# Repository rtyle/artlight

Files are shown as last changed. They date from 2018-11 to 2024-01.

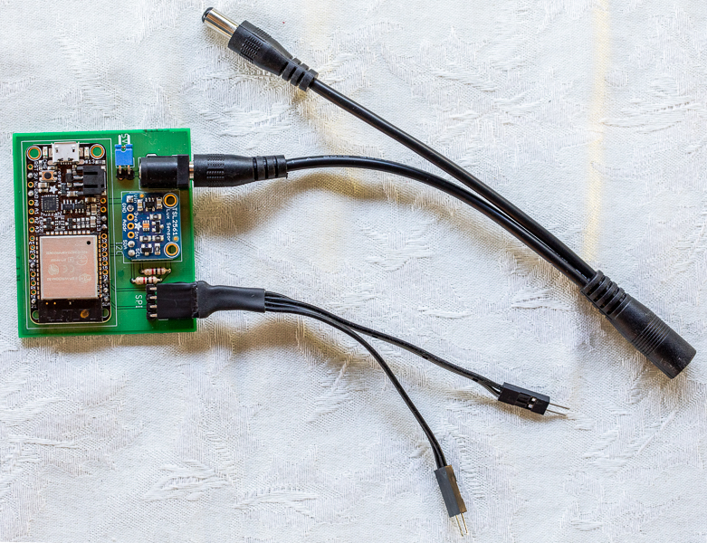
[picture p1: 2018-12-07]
project/doc/artlight.board.front.wired.jpg

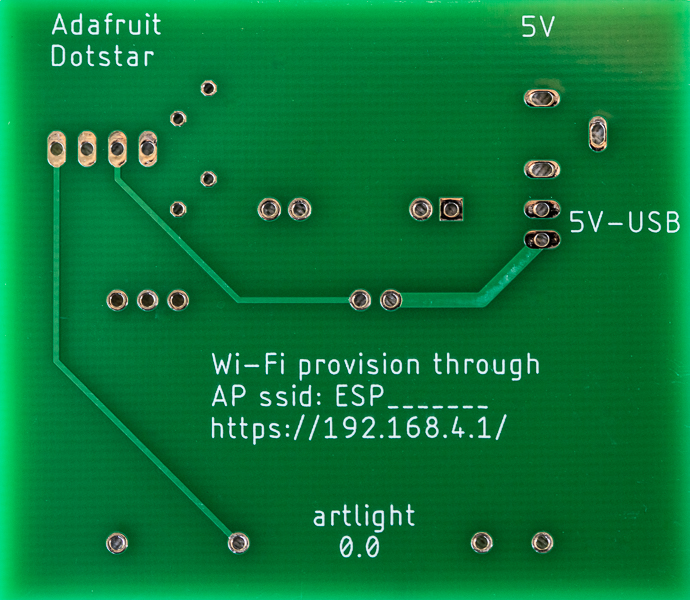
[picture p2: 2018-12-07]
project/doc/artlight.board.back.raw.jpg

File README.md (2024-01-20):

# artlight
This repository supports similar applications that artfully animate light.

Currently, there is a cornhole, wall clock, nixie tube clock and golden clock application supported by this repository.

Golden clock (LED sunflower): https://youtu.be/tHdfZooGRxo

Nixie tube clock: https://youtu.be/5ZdNDDC60QM

Wall clock: https://youtu.be/0ISKXnE9frU

## Parts

### Golden Clock Parts

* [5V 20W power supply](https://www.digikey.com/en/products/detail/cui-inc/SWI25-5-N-P5/7070092)
* [TinyPICO ESP32 development board](https://www.adafruit.com/product/4335)
* SMD 0.1" pin headers for mounting TinyPICO to TinyPICO IO PCB
* 2 position JST PH connection header (bundled in TinyPICO ESP32 development board package) for +5V TinyPICO power
* [3 position JST SH connection header](https://www.digikey.com/en/products/detail/jst-sales-america-inc/SM03B-SRSS-TB(LF)(SN)/926874) for LED SPI signals
* [4 position JST SH connection header](https://www.digikey.com/en/products/detail/sparkfun-electronics/PRT-14417/7652746) for I2C interface with light sensor
* 1024 [SK9822 5050 LEDs](https://www.amazon.com/gp/product/B07QXJSNLN)
* [Barrel connector jack](https://www.digikey.com/product-detail/en/cui-devices/PJ-036AH-SMT-TR/CP-036AHPJCT-ND/1530994) for +5V LED power
* [3 position 0.1" horizontal connection header](https://www.digikey.com/en/products/detail/harwin-inc/M20-8890345/6565716) for LED SPI signals
* [TSL2591 light sensor](https://www.digikey.com/en/products/detail/adafruit-industries-llc/1980/4990786)
* Appropriate cables and connectors for wiring harness
* [12" interior picture frame](https://www.etsy.com/listing/943351523/round-craft-frame-hump-profile-1-14)

### Nixie Tube Clock Parts

* [Bill of Materials](https://github.com/rtyle/artlight/blob/master/easyeda/projects/nixie/bom.csv), plus...
* [AC to 12V DC 1A wall mount power adapter](https://www.digikey.com/product-detail/en/cui-inc/SWI10-12-N-P5/102-4138-ND/6618698)
* 2 [Harwin 15 pin 2.54mm pitch](https://www.mouser.com/ProductDetail/855-M20-8771546) for SMT mount of Huzzah32 board
* 44 [Harwin H3161-05](https://www.digikey.com/product-detail/en/harwin-inc/H3161-05/952-2204-ND/3728169) sockets for nixie tube pins

Optional off-board ambient light sensor for automatic dimming
* [TSL2591 high dynamic range digital light sensor](https://www.adafruit.com/product/1980)
* [SparkFun Qwiic adapter](https://www.sparkfun.com/products/14495) TSL2591 qwiic mount
* 4 [Jumper SSH-003T-P0.2-H X2 12"](https://www.digikey.com/product-detail/en/jst-sales-america-inc/ASSHSSH28K305/455-3077-ND/6009453) TSL2591 qwiic cable
* 2 [Connector housing SH 4pos 1mm white](https://www.digikey.com/product-detail/en/jst-sales-america-inc/SHR-04V-S/455-1394-ND/759883) TSL2591 qwiic connectors

Optional on-board motion sensor plugin module for automatic on/off control
* [PIR detector I2C module](https://www.holtek.com/productdetail/-/vg/7M21x6)
* [Preci-Dip 851-87-006-10-001101 PCB connector](https://www.digikey.com/product-detail/en/preci-dip/851-87-006-10-001101/1212-1350-ND/3757600) PIR I2C mount

Optional base (something is required)
* 1 foot [Cast acrylic tubing 2.000" OD x .250" wall thickness](), cut into 9/16" slices. Four used as pedestals under PCB's nixie tubes.

### Cornhole and Wall Clock Parts

#### Cornhole and Wall Clock Common Parts

* [ESP32 board](https://www.adafruit.com/product/3405)
* [TSL2561 digital luminosity sensor breakout](https://www.adafruit.com/product/439)
* [DotStar digital LED strips](https://www.adafruit.com/product/2241)
* [2.1mm DC barrel jack (through hole)](https://www.adafruit.com/product/373)
* [Wi-Fi range extender (optional)](https://www.amazon.com/gp/product/B072MH1434)

#### Wall Clock Specific Parts

Additional parts for the clock application are
* [40 inch metal wall art](https://www.etsy.com/listing/614388701/round-metal-wall-art-perfect)
* [Custom PCB board for microprocessor](https://github.com/rtyle/artlight/blob/master/eagle/projects/artlight/artlight.brd)
* [Custom PCB board for 12 o'clock ray](https://github.com/rtyle/artlight/blob/master/eagle/projects/ray/ray0.brd)
* [Custom PCB board for other rays](https://github.com/rtyle/artlight/blob/master/eagle/projects/ray/ray.brd)
* [Mounting tape](https://www.amazon.com/gp/product/B00PKI7IBG)
* [Power supply](https://www.adafruit.com/product/1466)
* [Power Y splitter](https://www.amazon.com/gp/product/B06Y5GP7SF)
* [2.1mm DC barrel jack (surface mount)](https://www.sparkfun.com/products/12748)

#### Cornhole Specific Parts

Additional parts for the cornhole application are
* Cornhole board
* [Custom PCB board](https://github.com/rtyle/artlight/blob/master/eagle/projects/artlight/artlight.cornhole.brd)
* [Cornhole LED ring](https://www.amazon.com/gp/product/B01N7SRCQJ)
* [IR break beam sensor](https://www.adafruit.com/product/2168)
* [Vibration sensor](https://www.adafruit.com/product/1766)
* [On/off RGB switch](https://www.adafruit.com/product/3424)
* [Momentary RGB switch](https://www.adafruit.com/product/3423)
* [NPN bipolar transistors](https://www.adafruit.com/product/756)
* [Resistors](https://www.adafruit.com/product/2784)
* [Power bank](https://www.amazon.com/gp/product/B072MH1434)
* [Magnetic mount](https://www.amazon.com/gp/product/B01M0DUVZV)

## Construction

The PCB components were soldered on their respective boards.
When Huzzah32 is powered by USB cable, the 5V power jumper must first be removed.

### Golden Clock Construction

[LED PCB design files](https://github.com/rtyle/artlight/tree/master/easyeda/projects/golden)
and
[TinyPICO IO PCB design files](https://github.com/rtyle/artlight/tree/master/kicad/projects/golden/tinypico-io)

Solder LEDs and connectors to LED PCB.
Solder TinyPICO and connectors to TinyPICO IO PCB.
Build wire harness as necessary for mounting.

### Nixie Tube Clock Construction

[PCB design files](https://github.com/rtyle/artlight/tree/master/easyeda/projects/nixie)

For structural integrity, use a thick (>= 2.0mm) PCB.
Order PCB with a solder paste stencil.
Use the stencil to distribute solder paste for all components under the nixie tubes and solder them with a hot air gun.
Solder all other components individually, as appropriate.
Press in pin sockets and solder from the bottom.
Mount nixie tubes and place PCB on acrylic pedestals.

*WARNING*: The nixie tubes run at 170 volts.
To reduce exposure, do not plug in until tubes are mounted and PCB is placed on acrylic pedestals.

### Wall Clock Construction

[PCB design (artlight.\*) files](https://github.com/rtyle/artlight/tree/master/eagle/projects/artlight)
with
[boards for mounting LED strips on rays](https://github.com/rtyle/artlight/tree/master/eagle/projects/ray)

The microprocessor board is mounted on the back of the art with its luminosity sensor peeking through a hole drilled in the center.
Power is routed and split between the microprocessor and 12 o'clock ray boards.
SPI signals used to animate the individually addressable LEDs are cabled from the microprocessor board to the 12 o'clock board.

LED strips are mounted to the back of the wall art.
To reduce wiring complexity, the 12 rays are supported by PCBs.
12 o'clock is different so there is a special board for it.
Each ray is cut to length, an LED strip is cut to match, mounted with tape and soldered at the ends with LEDs advancing toward the center.
The ray boards are then mounted to the back of the art using more of the same tape.
Small strips are cut to bridge the arcs between ray bases, taped and soldered in place with LEDs advancing clockwise (from front!).
Starting at 12 o'clock, strips are cut and joined together with wire to skirt the perimeter of the art (clockwise, from front).
Only clock and data signals need to tunnel under the rays as 5V and GND can be tapped from the LED strip edges of adjacent rays.

### Cornhole Construction

[PCB design (artlight.cornhole.\*) files](https://github.com/rtyle/artlight/tree/master/eagle/projects/artlight)

The power bank is mounted with strong magnets under the board so that it might easily be unplugged, removed, charged, replaced and plugged back in.
Power from it may be switched on and off (with the on/off switch).
Switched power is split between the microprocessor board, the ring LED strip and the high side of the RGB LEDs in all the switches.

The R, G and B LEDs in the switches are separtely pulse-width-modulated (PWM) to mix the preferred color of each.
PWM switching is controlled indirectly through transistor circuits wired to the low side of the RGB LEDs of each switch.
The momentary switch outputs (closed to ground) are wired to the microprocessor board inputs dedicated for them.

Vibration sensors are strategically placed (for best performance) under the board.
The vibration sensor part may be changed to affect its sensitivity.
Their shared (parallel) output (closed to ground) is wired to the microprocessor board input dedicated for them.

IR break beam sensors are mounted across the cornhole ring for the best coverage (2 orthogonal pairs seems adequate).
Their shared (parallel) output (closed to ground) is wired to the microprocessor board input dedicated for them.

The LEDs that come with the cornhole LED ring are replaced with a clockwise (from the top) strip of 80 individually addressable LEDs.
Their control lines are wired to the microprocessor board output dedicated for them.
The ring is mounted under the board.
For best results, the material above the LED ring should be transparent (for example, an acrylic ring)
so that the lights under the board can be seen from above.

## Use

Applications must be provisioned on a Wi-Fi LAN.
Until this is done, they will offer their own Wi-Fi access point where they can be configured securely by a web browser (https://192.168.4.1).
The SSID and password for Wi-Fi access must be entered.
Optionally, an mDNS hostname may be given.

The reach of your Wi-Fi LAN may need to be increased to reach these devices.
This is best done by repositioning the devices and/or Wi-Fi access points.
If necessary, deploy a Wi-Fi range extender.

Once provisioned, preferences may be set for each application by pointing a web browser to the device (http://\<device\>/).
If supported, the mDNS hostname may be used to resolve the device address;
otherwise, the leased IP address will have to be resolved (perhaps manually) depending on the capabilities of the LAN's DHCP/DNS services.

The preferences page may be filled using "factory" default values or with the current values.
Changes to most will take effect immediately.
If not, then they will take effect when the form is submitted.

Preferences may be used to customize the presentation.
Brightness parameters may be set which may include use of the luminosity sensor.
The mDNS hostname of the board may be changed.
Parameters may be set in order to accurately present time in the given time zone.
Over-the-air software updates may also be performed.

## Golden Clock Use

It's "golden" because the LED layout that produces the spirals is based on the [golden ratio](https://en.wikipedia.org/wiki/Golden_ratio).

In clock mode, the length, width, curl, shape and color of each hand may be customized. During the first minute of each hour, the minute and second hands are suppressed and the hour hand is etched into a matching randomized swirling pattern.

In swirl mode, the randomized swirling pattern cycles through six different minute-long phases, each aligned to a particular set of spirals.

The number of spirals in each set are [Fibonacci numbers](https://en.wikipedia.org/wiki/Fibonacci_number) (13, 21, 34, 55, 89, 144).
The lower the number, the tighter (curlier) the spirals in the set.
Of all the Fibonacci numbers, these ones resolve best on a layout with this number of LEDs.
By default, the sets with 21, 55 and 144 spirals are used to resolve the hour, minute and second hands because they all curve the same way and most all are sufficient to resolve the units of their measure.
Unfortunately, 55 is not quite enough resolution for 60 minutes but it looks better than the spiral set of 89 because that curves the other way.
In any case, you can choose what you like.

A high quality power supply is required to power both the microcontroller and the LEDs.
It may be necessary to use separate power supplies for these.
If so, they must tolerate having their grounds tied together.

## Nixie Tube Clock Use

The bottom dot of the colon pulses at 30 beats per minute (a second on and a second off).
The top dot of the colon pulses at 31 beats per minute.
This results in pulsing dots that are in phase at the beginning of the minute.
They separate more as mid-minute is approached and come back together again as the next minute is approached.
Thus the colon is a very crude seconds display.

Dimming controls should be slid all the way to the left to disable dimming; otherwise, dimming will start to occur as it gets dark.
The further to the right the dimming control is set, the more dimming will be done.
When slid all the way to the right, the controlled element will dim to black when the room is black.

In an effort to combat [nixie tube cathode poisoning](https://www.google.com/search?q=nixie+tube+cathode+poisoning)
the clock will not display minutes during the first minute of every hour.
Instead, the normal minutes-places will cycle through digits that are not normally used there.
For hours less than 10, the tens-of-hours place will similarly cycle.
The display can also be temporarily put in a Clean mode (or other modes) until expectations are met.

## Wall Clock Use

There are no additional preferences for the clock application.

The clock will present time by animating hour, minute and second indicators using the LEDs mounted to the back of the art.
Hour and minute indicators will animate up and down the rays and across the inner arcs that connect them.
The second indicator will sweep across the perimeter.

## Cornhole Use

The cornhole "preferences" page may be used to keep score.
In fact, unless explicitly accessed through a URL with a preferences path (http://\<device\>/preferences), scoring is the only thing allowed.

Changing most preferences (including scoring) will be shared between boards that have been configured to use the same network port number.
For this to work effectively, only the two boards used in a cornhole game should share the same port number and each must be reachable from the other on the same network.

A preference may be used to control what the ring LED strip indicates:
* The score of each team
* The time
* Various animations

Regardless of what the ring indicates:

A short press of a momentary switch will increment the score of the associated team.
A long press of a momentary switch will decrement the score of the associated team while held.
While decrementing, if the other switch is down too then the score is reset to 0 (hold both to reset both to 0).

Vibration from the board will cause a short "lightning strike" animation to be presented over the existing ring indication.
A break in the ring's IR beam sensors will cause a short "fireworks" animation to be presented over the existing ring indication.

## Software Build, Deploy and Monitor

These projects were built on a Fedora Linux platform.
Your mileage may vary elsewhere.

Get artlight source code with its dependencies

    git clone http://github.com/rtyle/artlight.git
    cd artlight
    git submodule update --init --recursive
    (cd esp-idf; git apply ../time.c.patch)
  
[Create certificates](https://github.com/rtyle/artlight/blob/master/project/README.certificates.txt)

Install tools required by esp-idf in esp-idf-tools.

    IDF_TOOLS_PATH=esp-idf-tools esp-idf/install.sh

(Re)establish build environment.

    . esp-idf-export.sh

Select application (choose one).

    application=clock
    application=cornhole
    application=golden
    application=nixie

Build application.

    (cd project; ArtlightApplication=$application idf.py fullclean reconfigure build)

Grant user access to USB serial devices then **relogin** to get access.

    sudo usermod -a -G dialout $USER

Identify serial port to connected device.
For example,

    port=/dev/ttyUSB0

Prepare connected device and deploy application.

    (cd project; idf.py -p $port erase_flash erase_otadata)
    (cd project; idf.py -p $port flash)

Monitor serial output from device.

    (cd project; idf.py -p $port monitor)

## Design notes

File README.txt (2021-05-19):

# git

	git clone git@github.com:rtyle/artlight.git

	cd artlight

# esp-idf

	# give $USER access to /dev/ttyUSB* and relogin
	# this is needed to allow for USB communication with esp32
	sudo usermod -a -G dialout $USER

	# toolchain prerequisites
	# https://docs.espressif.com/projects/esp-idf/en/stable/esp32/get-started/linux-setup.html

		sudo dnf install git wget flex bison gperf python3 python3-pip python3-setuptools cmake ninja-build ccache dfu-util libusbx

	# esp-idf
	# https://docs.espressif.com/projects/esp-idf/en/stable/esp32/get-started/index.html#get-started-get-esp-idf

		# install esp-idf as a submodule under project
		git submodule add https://github.com/espressif/esp-idf.git

		# update now (and/or later)

			(
				cd esp-idf
				git fetch
				git checkout v4.3-beta3
				git submodule update --init --recursive
			)

# esp-idf-tools

	# install tools required by esp-idf in esp-idf-tools
	IDF_TOOLS_PATH=esp-idf-tools esp-idf/install.sh

	install /dev/stdin esp-idf-export.sh <<EOF
export IDF_TOOLS_PATH=$(realpath esp-idf-tools); . esp-idf/export.sh
EOF

	# (re)establish this environment for idf.py and eclipse actions

		. esp-idf-export.sh

	echo esp-idf-tools > .gitignore

# eclipse

	sudo dnf install eclipse eclipse-cdt eclipse-mpc

	# fedora 34 packaged eclipse does not work with espressif/idf-eclipse-plugin
	# https://github.com/espressif/idf-eclipse-plugin/issues/260
	# download from eclipse.org

		curl https://www.eclipse.org/downloads/download.php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 | tar xzf -
		mv eclipse ~/eclipse-2021-03

	# get rid of old eclipse artifacts

		rm -rf ~/.{eclipse,p2}

# https://docs.espressif.com/projects/esp-idf/en/latest/get-started/eclipse-setup.html

	echo .metadata >> .gitignore

	(. esp-idf-export.sh; ~/eclipse-2021-03/eclipse >/dev/null 2>&1 &)

		#! set workspace to here

		Help: Install New Software...: Add...: 

			# espressif/idf-eclipse-plugin

				Name:		espressif/idf-eclipse-plugin latest
				Location:	https://dl.espressif.com/dl/idf-eclipse-plugin/updates/latest/

				Add

				X Espressif IDF

				Install anyway
				Restart Now

		File: New: Project...

			Wizard: Espressif: Espressif IDF Project
			Project name: project

		Project Explorer: <project>

			toolbar: Launch Target
				Name:		esp32
				IDF Target:	esp32
				Serial Port:	/dev/ttyUSB1

			toolbar: Build

			toolbar: Open a Terminal
				Choose terminal:	ESP-IDF Serial Monitor
					this doesn't work
				Choose terminal:	Serial Terminal

			toolbar: Launch in 'Run' mode

		<project>: Run As: Run Configurations...
			ESP-IDF Application
				project
					Common
						Display in favorites menu
							0 Debug
							X Run
					Apply
					Close

		<project>: Debug As: Debug Configurations...
			ESP-IDF GDB OpenOCD Debugging
				New Configuration
					Name:	project debugger
					Debugger
						OpenOCD Setup
							Executable path:	openocd
							Config options:		-f board/esp32-wrover-kit-3.3v.cfg
						GDB Client Setup
							Actual executable:	xtensa-esp32-elf-gdb
					Startup
						Initialization Commands
							0 Enable ARM semihosting
					Common
						Display in favorites menu
							X Debug
							0 Run
					Apply
					Close

		Project Explorer: <project>

			toolbar: Launch Configuration: project debugger
			toolbar: Launch Mode: Debug
			toolbar: Launch in 'Debug' mode

				# auto change to debug perspective
				# find code stopped at app_main entry point

		exit eclipse

	rm -rf project/build
	rm project/sdkconfig*

	echo build	>> project/.gitignore
	echo sdkconfig	>> project/.gitignore
	echo *.old	>> project/.gitignore
	echo *.swp	>> project/.gitignore

	git add README.txt .gitignore project
	git commit -m 'idf-eclipse-plugin'

eclipse preferences

	General: Editors: Text Editors
		Displayed tab width:	8
		X Show print margin
		X Show line numbers
		X Show whitespace characters

	C/C++: Code Style: Formatter
		Active profile:	K&R [built-in]: Edit...
			Profile Name: K&R [built-in] sw=4 ts=8
				Tab policy:		Mixed
				Indentation size:	4
				Tab size:		8

	exit eclipse

	git add README.txt
	git commit -m 'eclipse preferences'

configuring build type and
flashing from command line
	
	# pick one
	application=clock
	application=cornhole
	application=nixie
	application=golden

	# clean
	(cd project; ArtlightApplication=$application idf.py fullclean)

	# reconfigure for build type
	(cd project; ArtlightApplication=$application idf.py reconfigure -DCMAKE_BUILD_TYPE=Release)
	(cd project; ArtlightApplication=$application idf.py reconfigure -DCMAKE_BUILD_TYPE=Debug)

	# build
	(cd project; idf.py build)

	# identify serial port to connected device
	port=/dev/ttyUSB0

	# prepare connected device and deploy application
	(cd project; idf.py -p $port erase_flash erase_otadata)
	(cd project; idf.py -p $port flash)

	# monitor serial output from device
	(cd project; idf.py -p $port monitor)

# OTA service

	(cd project/build; openssl s_server -WWW -key ../certificates/ota_ca_key.pem -cert ../certificates/ota_ca_cert.pem)

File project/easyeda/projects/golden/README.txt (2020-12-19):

golden.html is a way to play with the PCB layout in a web browser
as well as a way to playing with animation of such.

While pcb.json can be uploaded into the EasyEDA online editor ...
https://easyeda.com/editor
... it is too large to save to cloud storage.
Because it cannot be saved first, the online editor will not make gerber files.
Instead, the EasyEDA offline editor must be used.

Unfortunately, the size of the gerber.zip archive created by the offline editor
is too large for JLCPCB.
The contents of this EasyEDA gerber.zip archive is captured
under the gerber directory.
7zip was used to remove the TopSilk layer and recompress it
to a smaller size

	(cd gerber; 7z a ../gerber.zip $(ls Gerber* | grep -v TopSilk)

The SK9822 LED LINK symbol, used for each LED in the schematic and pcb, is captured in

	SK9822LEDLINK.json

The SK9822 LED LINK symbol is referenced by its uuid in the following scripts

	createStrip.js	create and layout all the LEDs so that they are linked
	orderStrip.js	reposition LEDs according to the itemOrder they were created in

The following scripts were used to layout the PCB

	goldenPath.js		wend the ordered LEDs through their places
	goldenRing.js		create a COPPERAREA that covers all the LEDs
	centerOfSelected.js	used to calculate center of board outline

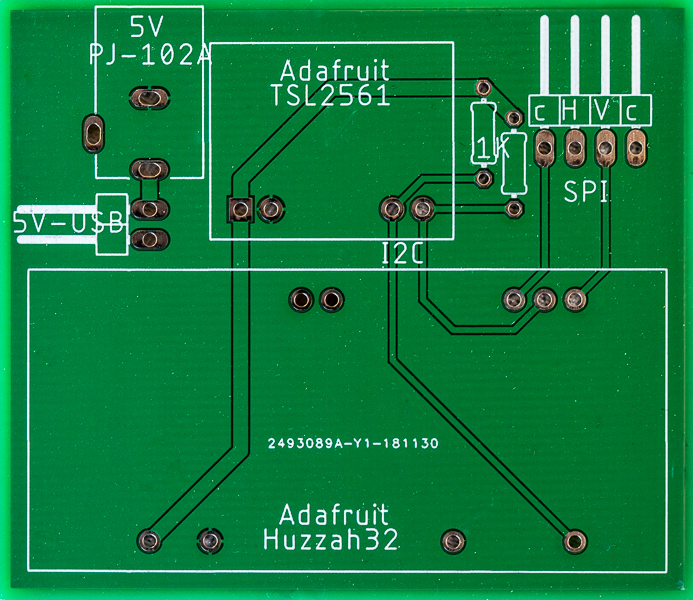
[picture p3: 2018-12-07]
project/doc/artlight.board.front.raw.jpg

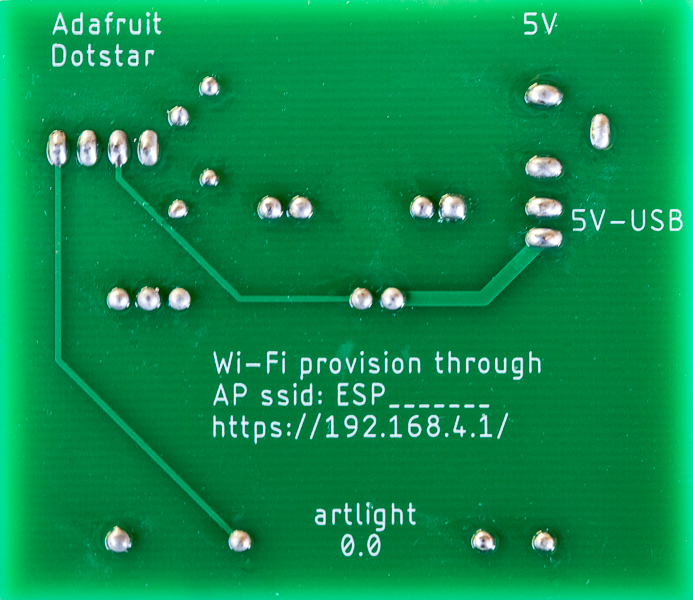
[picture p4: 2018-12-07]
project/doc/artlight.board.back.cooked.jpg

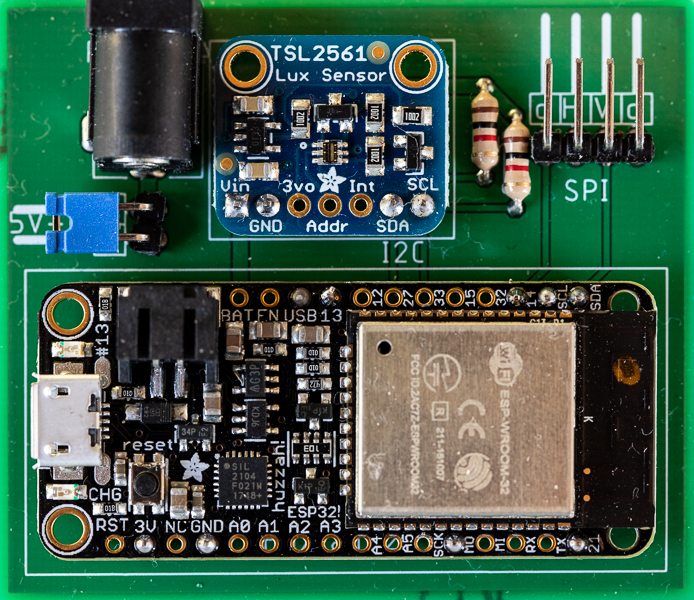
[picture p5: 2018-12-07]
project/doc/artlight.board.front.cooked.jpg

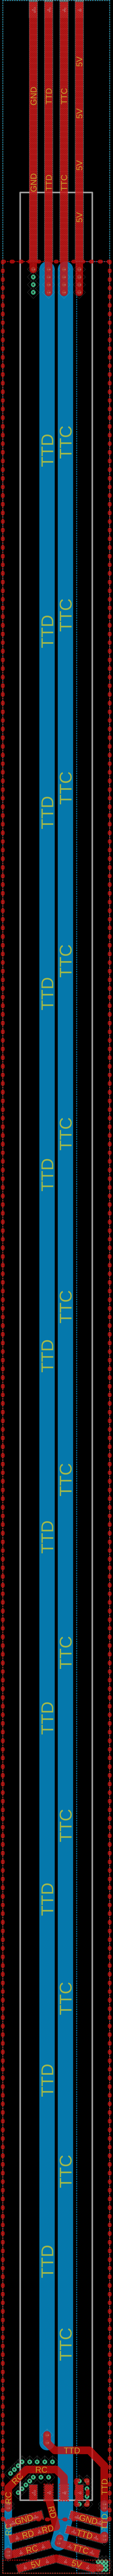
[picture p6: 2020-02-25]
project/eagle/projects/ray/ray.png

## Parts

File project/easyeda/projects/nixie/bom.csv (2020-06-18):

ID | Name | Designator | Footprint | Quantity | Manufacturer Part | Manufacturer | Supplier | Supplier Part | link
1 | R|Z568M nixie tube | NX00,NX10,NX20,NX30 | R|Z568M NIXIE TUBE BOTTOM VIEW | 4 |  |  |  |  | https://www.daliborfarny.com/product/rz568m-nixie-tube/
2 | Huzzah32 | MPU0 | HUZZAH32 SMT | 1 | 3405 | Adafruit | Digi-Key | 1528-2181-ND
3 | V78E05-1000-SMT | PS+5V | CUI V78E-1000-SMT | 1 | V78E05-1000-SMT | CUI | Digi-Key | 102-5033-1-ND | https://www.digikey.com/product-detail/en/cui-inc/V78E05-1000-SMT-TR/102-5033-1-ND/9649684
4 | 8.2K 1W | R0A,R1A,R2A,R3A | R2512 | 4 | CRCW25128K20JNEG | Vishay Dale | Digi-Key | 541-8.2KXCT-ND | https://www.digikey.com/product-detail/en/vishay-dale/CRCW25128K20JNEG/541-8-2KXCT-ND/1178603
5 | 22uF 16V | CPS+5VO | C1210 | 1 | C1210C226K4RAC7800 | KEMET | Digi-Key | 399-11662-1-ND | https://www.digikey.com/product-detail/en/kemet/C1210C226K4RAC7800/399-11662-1-ND/5023257
6 | R|Z568M colon tube | NXC0 | R|Z568M COLON TUBE BOTTOM VIEW | 1 | R|Z568M colon tube | Dalibor Farny |  |  | http://docs.daliborfarny.com/doc/separator-tube-rz568m/
7 | SK9822 LED | D00,D01,D10,D11,D20,D21,D30,D31 | SK9822 LED | 8 | 2343 | Adafruit | Digi-Key | 1528-1436-ND | https://www.digikey.com/products/en?mpart=2343&v=1528
8 | 68K 1W | RNCL,RNCR | R2512 | 2 | CRCW251268K0JNEG | Vishay Dale | Digi-Key | 541-68KXCT-ND | https://www.digikey.com/product-detail/en/vishay-dale/CRCW251268K0JNEG/541-68KXCT-ND/1178625
9 | 10uF 50V | CPS+5VI | C1210 | 1 | C1210C106K5RACTU | KEMET | Digi-Key | 399-11629-1-ND | https://www.digikey.com/product-detail/en/kemet/C1210C106K5RACTU/399-11629-1-ND/4918885
10 | NXP PCA9685 TSSOP28 | U00,U10,U20,U30 | SOT361-1 | 4 | PCA9685PW/Q900,118 | NXP USA Inc. | Digi-Key | 568-5931-1-ND | https://www.digikey.com/product-detail/en/nxp-usa-inc/PCA9685PW-Q900-118/568-5931-1-ND/2531218
11 | SMMBTA42LT1G | Q00,Q01,Q02,Q03,Q04,Q05,Q06,Q07,Q08,Q09,Q10,Q11,Q12,Q13,Q14,Q15,Q16,Q17,Q18,Q19,Q1L,Q20,Q21,Q22,Q23,Q24,Q25,Q26,Q27,Q28,Q29,Q2R,Q30,Q31,Q32,Q33,Q34,Q35,Q36,Q37,Q38,Q39 | SOT-23-3_L2.9-W1.6-P1.90-LS2.8-BR | 42 | SMMBTA42LT1G | ON Semiconductor | Digi-Key | SMMBTA42LT1GOSCT-ND | https://www.digikey.com/product-detail/en/on-semiconductor/SMMBTA42LT1G/SMMBTA42LT1GOSCT-ND/8538921
12 | Holtek HT7M21xx | U1 | PRECI-DIP 851-87-006-40-001101 | 1 | HT7M21xx | Holtek | Mouser | HT7M21xx
13 | 1uF 16V | C00,C10,C20,C30 | C0603 | 4 | C0603C105K8RACTU | KEMET | Digi-Key | 399-11133-1-ND | https://www.digikey.com/product-detail/en/kemet/C0603C105K8RACTU/399-11133-1-ND/4357815
14 | 2.2uF 450V | CPS+170VO0 | C2220 | 1 | C5750X6S2W225K250KA | TDK Corporation | Digi-Key | 445-7781-1-ND | https://www.digikey.com/product-detail/en/tdk-corporation/C5750X6S2W225K250KA/445-7781-1-ND/2733853
15 | 0.1uF 630V | CPS+170VO1 | C1812 | 1 | CGA8N4X7R2J104K230KA | TDK Corporation | Digi-Key | 445-7922-1-ND | https://www.digikey.com/product-detail/en/tdk-corporation/CGA8N4X7R2J104K230KA/445-7922-1-ND/2781426
16 | NCH8200HV | PS+170V | NCH8200HV SMD | 1 | NCH8200HV | nixieclock.org | Amazon | B074S2T7X3 | https://www.amazon.com/%E3%80%90Genuine%E3%80%91NCH8200HV-Voltage-Module-Nixie-Clock/dp/B074S2T7X3
17 | Header-Male-2.54_1x2 | H0 | HARWIN M20-8890245 | 1 | M20-8890245 | Harwin | Digi-Key | 952-3231-ND | https://www.digikey.com/product-detail/en/harwin-inc/M20-8890245/952-3231-ND/6565715
18 | SM04B-SRSS-TB (LF)(SN) QWIIC | CN0 | CONN-SMD_4P-P1.00_SM04B-SRSS-TB(LF)(SN) | 1 | PRT-14417 | SparkFun Electronics | Digi-Key | PRT-14417-ND | https://www.digikey.com/product-detail/en/sparkfun-electronics/PRT-14417/PRT-14417-ND/7652746
19 | PJ-036AH-SMT-TR | J+12V | CUI PJ-036AH-SMT-TR | 1 | PJ-036AH-SMT-TR | CUI | Digi-Key | CP-036AHPJCT-ND | https://www.digikey.com/product-detail/en/cui-devices/PJ-036AH-SMT-TR/CP-036AHPJCT-ND/1530994
20 | 1K 1/10W | RI2C0CLK,RI2C0SDA,R00,R01,R02,R03,R04,R05,R06,R07,R08,R09,R10,R11,R12,R13,R14,R15,R16,R17,R18,R19,R1L,R20,R21,R22,R23,R24,R25,R26,R27,R28,R29,R2R,R30,R31,R32,R33,R34,R35,R36,R37,R38,R39 | R0603 | 44 | CRCW06031K00FKEA | Vishay Dale | Digi-Key | 541-1.00KHCT-ND | https://www.digikey.com/product-detail/en/vishay-dale/CRCW06031K00FKEA/541-1-00KHCT-ND/1179809
21 | 1K 0603 | RI2C1SDA | R0603 | 1 | CRCW06031K00FKEA | Vishay Dale | Digi-Key | 541-1.00KHCT-ND | https://www.digikey.com/product-detail/en/vishay-dale/CRCW06031K00FKEA/541-1-00KHCT-ND/1179809
22 | 1K 1206 | RI2C1CLK | R1206 | 1 | CRCW12061K00FKEA | Vishay Dale | Digi-Key | 541-1.00KFCT-ND | https://www.digikey.com/product-detail/en/vishay-dale/CRCW12061K00FKEA/541-1.00KFCT-ND/1181760

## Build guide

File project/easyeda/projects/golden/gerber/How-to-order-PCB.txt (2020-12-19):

How to Order PCB

Please refer to:
https://docs.easyeda.com/en/PCB/Order-PCB

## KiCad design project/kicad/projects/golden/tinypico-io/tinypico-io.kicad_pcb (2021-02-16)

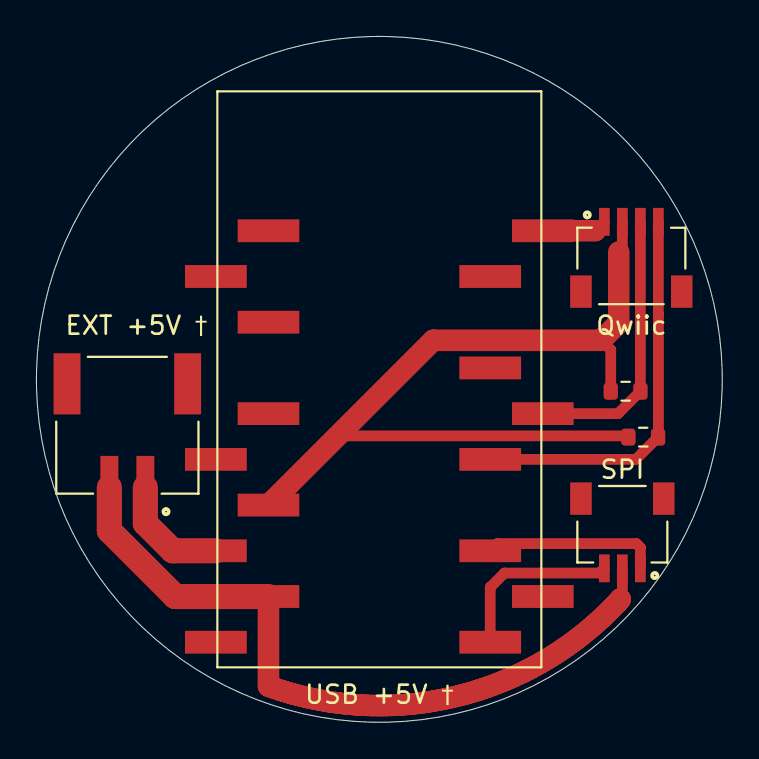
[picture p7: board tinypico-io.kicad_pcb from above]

Board: 2 copper layers, 38.1 x 38.1 mm, 6 parts (0 on the bottom side), 8 nets.

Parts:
J1: S2B-PH-SM4-TB(LF)(SN); JST_S2B-PH-SM4-TB(LF)(SN)
J2: SM03B-SRSS-TB(LF)(SN); JST_SM03B-SRSS-TB(LF)(SN)
J3: SM04B-SRSS-TB(LF)(SN); JST_SM04B-SRSS-TB(LF)(SN)
R1, R2: 1K; R_0603_1608Metric
U1: TSM-110-01-L-SV; TinyPICO

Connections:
+5V: J1.1, U1.3
/3V3: J3.2, R1.1, R2.1, U1.4
GND: J1.2, J2.2, U1.2
GND1: J3.1, U1.11
MOSI: J2.3, U1.20
SCK: J2.1, U1.18
SCL: J3.4, R2.2, U1.16
SDA: J3.3, R1.2, U1.15

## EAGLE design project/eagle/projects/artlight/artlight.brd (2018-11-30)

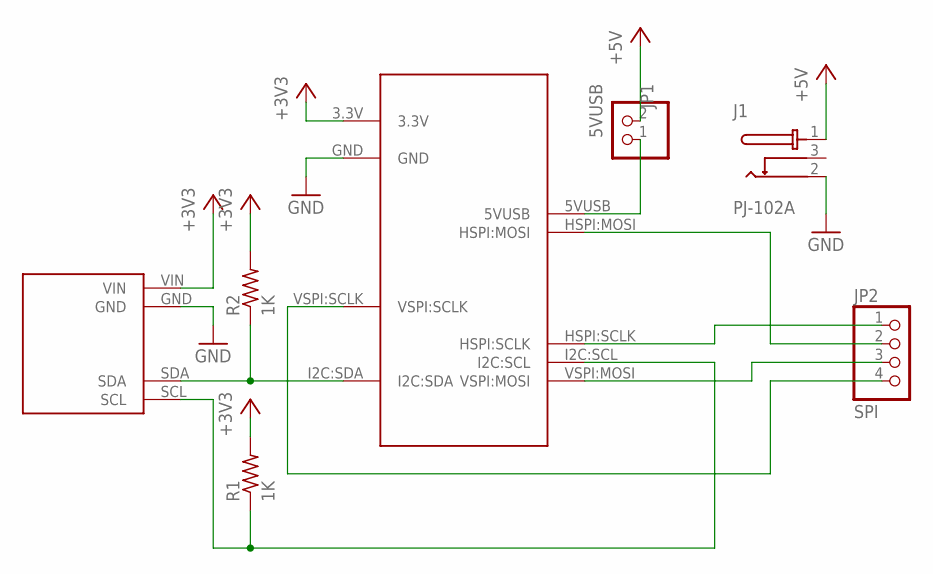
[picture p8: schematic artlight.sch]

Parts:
J1: PJ-102A; CUI_PJ-102A
JP1: 5VUSB; 1X02/90
JP2: SPI; 1X04/90
R1, R2: 1K; 0204/7
U$1: HUZZAH32-ARTLIGHT; FEATHERWING-ARTLIGHT
U$3: TSL2561-ARTLIGHT

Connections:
3: J1.3
5VUSB: JP1.1, U$1.5VUSB
+3V3: R1.2, R2.2, U$1.3.3V, U$3.VIN
+5V: J1.1, JP1.2
GND: J1.2, U$1.GND, U$3.GND
HSPI-MOSI: JP2.2, U$1.HSPI:MOSI
I2C-SCL: R1.1, U$1.I2C:SCL, U$3.SCL
I2C-SDA: R2.1, U$1.I2C:SDA, U$3.SDA
unnamed: JP2.3, U$1.VSPI:MOSI
unnamed: JP2.1, U$1.HSPI:SCLK
VSPI-SCLK: JP2.4, U$1.VSPI:SCLK

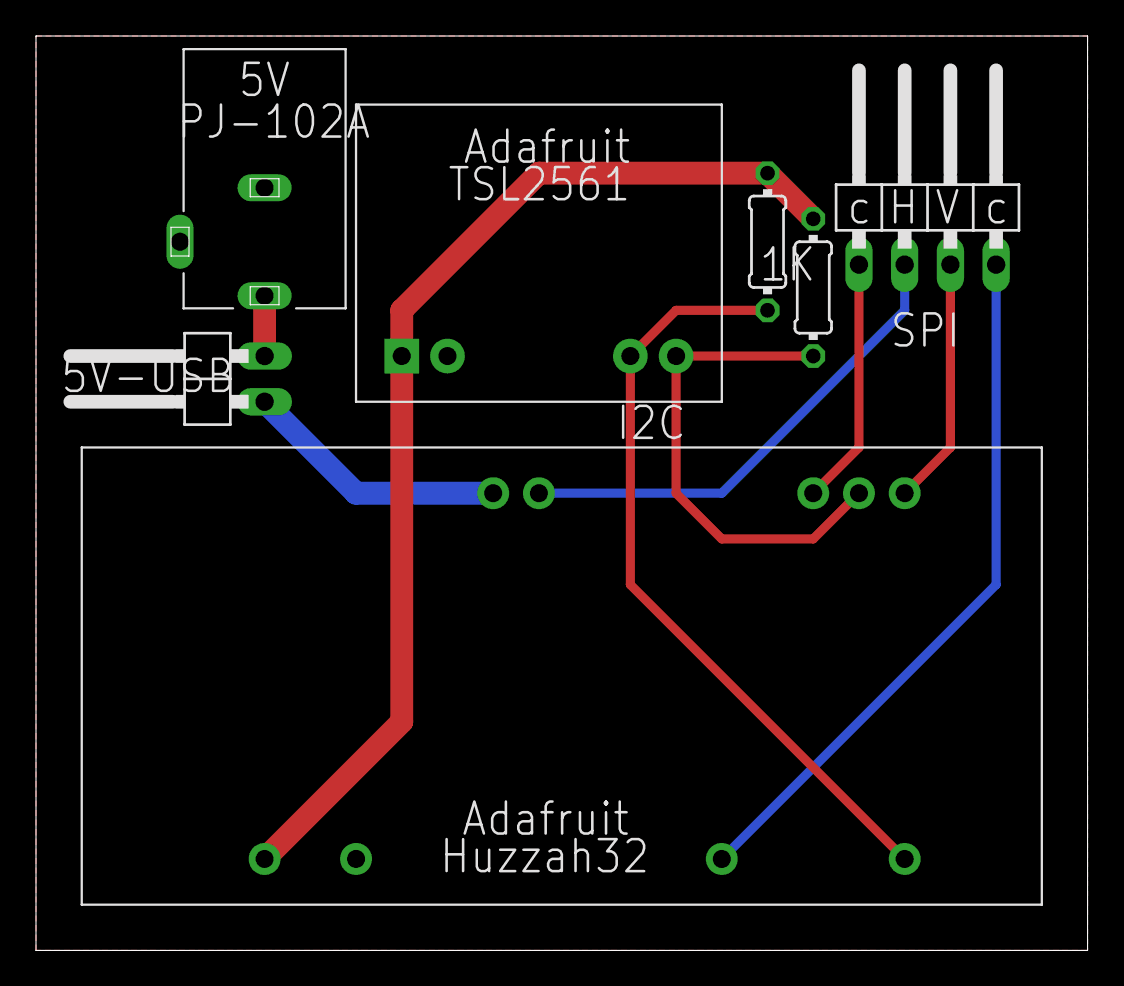
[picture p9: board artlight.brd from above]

Board: 2 copper layers, 58.4 x 50.8 mm, 7 parts (0 on the bottom side), 10 nets.

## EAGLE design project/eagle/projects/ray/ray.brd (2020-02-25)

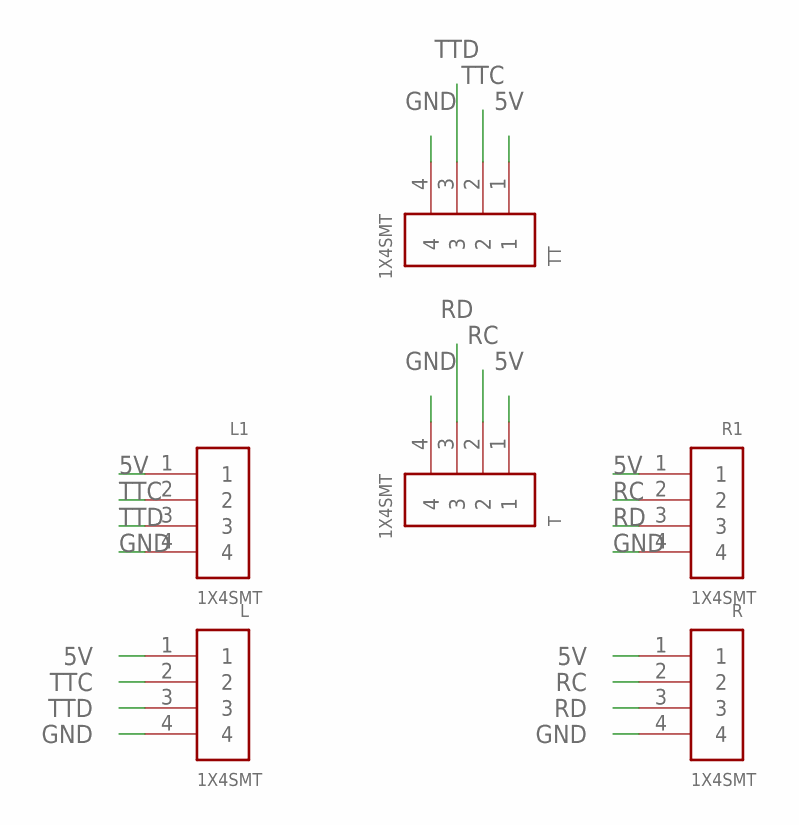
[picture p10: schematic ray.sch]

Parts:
L, L1: 1X4SMT; 1X4-SMT
R, R1: 1X4SMT; 1X4-SMT
T: 1X4SMT; 1X4-SMT
TT: 1X4SMT; 1X4-SMT

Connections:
5V: L.1, L1.1, R.1, R1.1, T.1, TT.1
GND: L.4, L1.4, R.4, R1.4, T.4, TT.4
RC: R.2, R1.2, T.2
RD: R.3, R1.3, T.3
TTC: L.2, L1.2, TT.2
TTD: L.3, L1.3, TT.3

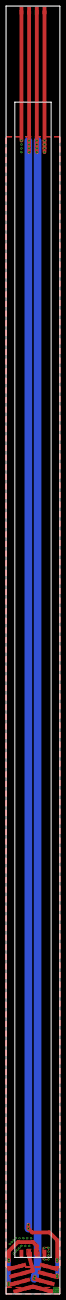
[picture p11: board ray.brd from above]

Board: 2 copper layers, 17.8 x 425.4 mm, 6 parts (0 on the bottom side), 6 nets.

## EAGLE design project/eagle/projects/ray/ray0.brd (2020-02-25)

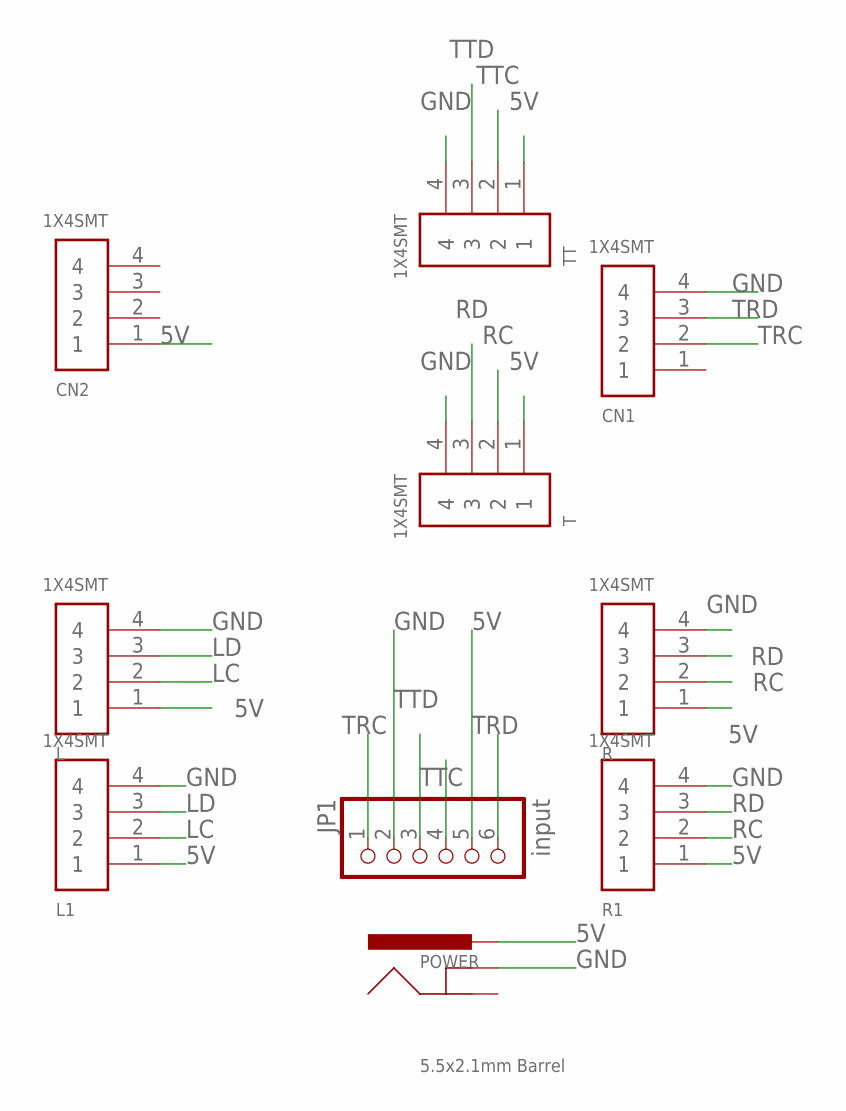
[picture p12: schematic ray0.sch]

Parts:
CN1, CN2: 1X4SMT; 1X4-SMT
JP1: input; 1X06
L, L1: 1X4SMT; 1X4-SMT
POWER: 5.5x2.1mm Barrel; POWER_JACK_SMD
R, R1: 1X4SMT; 1X4-SMT
T: 1X4SMT; 1X4-SMT
TT: 1X4SMT; 1X4-SMT

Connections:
5V: CN2.1, JP1.5, L.1, L1.1, POWER.VIN0 (PWR), POWER.VIN1 (PWR), R.1, R1.1, T.1, TT.1
GND: CN1.4, JP1.2, L.4, L1.4, POWER.GND (GNDBREAK), R.4, R1.4, T.4, TT.4
LC: L.2, L1.2
LD: L.3, L1.3
RC: R.2, R1.2, T.2
RD: R.3, R1.3, T.3
TRC: CN1.2, JP1.1
TRD: CN1.3, JP1.6
TTC: JP1.4, TT.2
TTD: JP1.3, TT.3

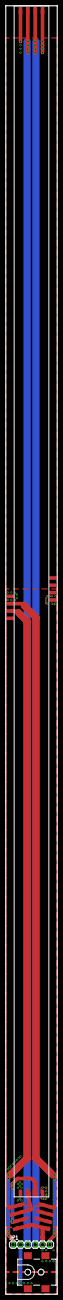
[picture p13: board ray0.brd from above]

Board: 2 copper layers, 17.8 x 445.5 mm, 10 parts (0 on the bottom side), 10 nets.

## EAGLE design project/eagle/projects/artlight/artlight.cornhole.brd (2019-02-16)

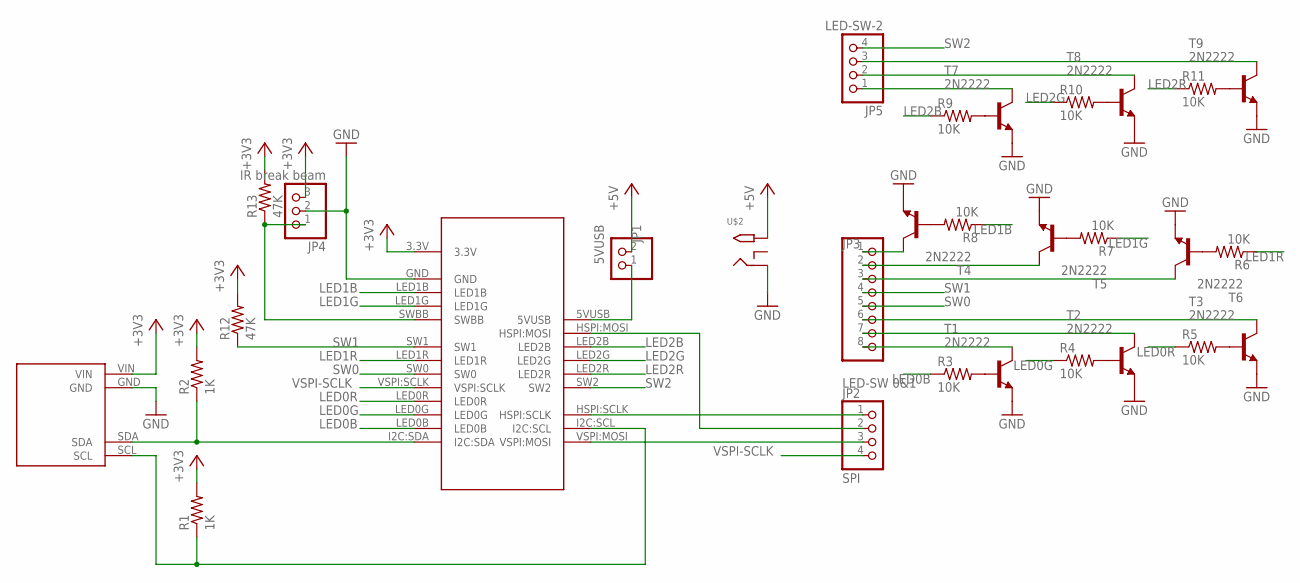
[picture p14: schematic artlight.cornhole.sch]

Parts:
JP1: 5VUSB; 1X02
JP2: SPI; 1X04
JP3: LED-SW 0&1; 1X08
JP4: IR break beam; 1X03
JP5: LED-SW-2; 1X04
R1, R2: 1K; 0204/7
R3, R4, R5, R6, R7, R8, R9, R10, R11: 10K; 0204V
R12, R13: 47K; 0204/7
T1, T2, T3, T4, T5, T6, T7, T8, T9: 2N2222; TO92-EBC-OVAL
U$1: HUZZAH32-ARTLIGHT.CORNHOLE; FEATHERWING-ARTLIGHT.CORNHOLE
U$2: 2.1MMJACKTHM; PJ-102A
U$3: TSL2561-ARTLIGHT

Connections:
5VUSB: JP1.1, U$1.5VUSB
+3V3: JP4.3, R1.2, R2.2, R12.2, R13.2, U$1.3.3V, U$3.VIN
+5V: JP1.2, U$2.TIP
GND: JP4.2, T1.E, T2.E, T3.E, T4.E, T5.E, T6.E, T7.E, T8.E, T9.E, U$1.GND, U$2.RING, U$3.GND
HSPI-MOSI: JP2.2, U$1.HSPI:MOSI
HSPI-SCLK: JP2.1, U$1.HSPI:SCLK
I2C-SCL: R1.1, U$1.I2C:SCL, U$3.SCL
I2C-SDA: R2.1, U$1.I2C:SDA, U$3.SDA
LED0B: R3.1, U$1.LED0B
LED0B-BASE: R3.2, T1.B
LED0B-PIN: JP3.8, T1.C
LED0G: R4.1, U$1.LED0G
LED0G-BASE: R4.2, T2.B
LED0G-PIN: JP3.7, T2.C
LED0R: R5.1, U$1.LED0R
LED0R-BASE: R5.2, T3.B
LED0R-PIN: JP3.6, T3.C
LED1B: R8.1, U$1.LED1B
LED1B-BASE: R8.2, T4.B
LED1B-PIN: JP3.1, T4.C
LED1G: R7.1, U$1.LED1G
LED1G-BASE: R7.2, T5.B
LED1G-PIN: JP3.2, T5.C
LED1R: R6.1, U$1.LED1R
LED1R-BASE: R6.2, T6.B
LED1R-PIN: JP3.3, T6.C
LED2B: R9.1, U$1.LED2B
LED2B-BASE: R9.2, T7.B
LED2B-PIN: JP5.1, T7.C
LED2G: R10.1, U$1.LED2G
LED2G-BASE: R10.2, T8.B
LED2G-PIN: JP5.2, T8.C
LED2R: R11.1, U$1.LED2R
LED2R-BASE: R11.2, T9.B
LED2R-PIN: JP5.3, T9.C
SW0: JP3.5, U$1.SW0
SW1: JP3.4, R12.1, U$1.SW1
SW2: JP5.4, U$1.SW2
SWBB: JP4.1, R13.1, U$1.SWBB
VSPI-MOSI: JP2.3, U$1.VSPI:MOSI
VSPI-SCLK: JP2.4, U$1.VSPI:SCLK

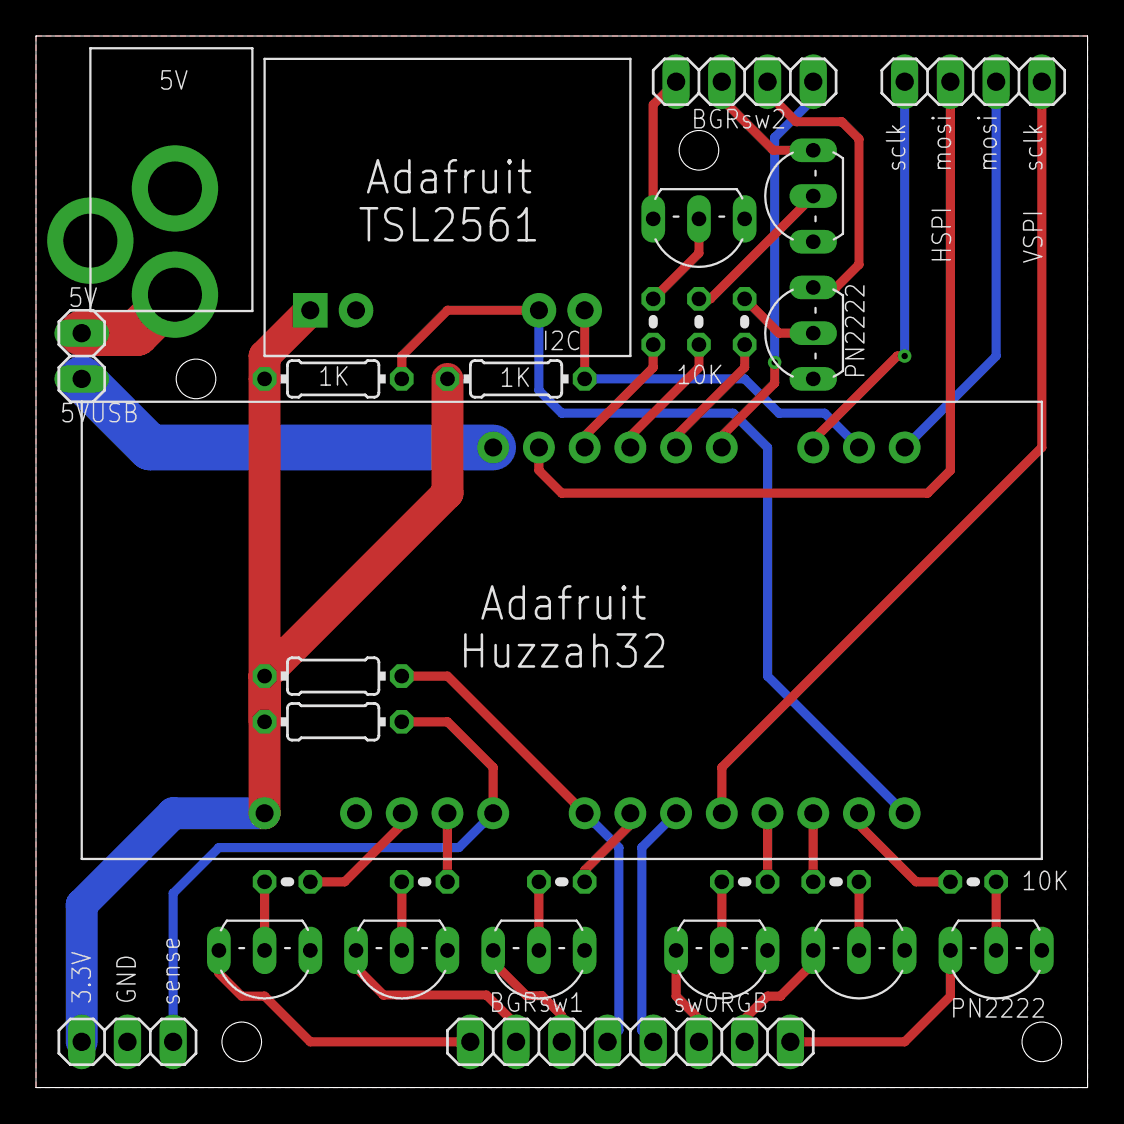
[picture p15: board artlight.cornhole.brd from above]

Board: 2 copper layers, 58.4 x 58.4 mm, 30 parts (0 on the bottom side), 41 nets.

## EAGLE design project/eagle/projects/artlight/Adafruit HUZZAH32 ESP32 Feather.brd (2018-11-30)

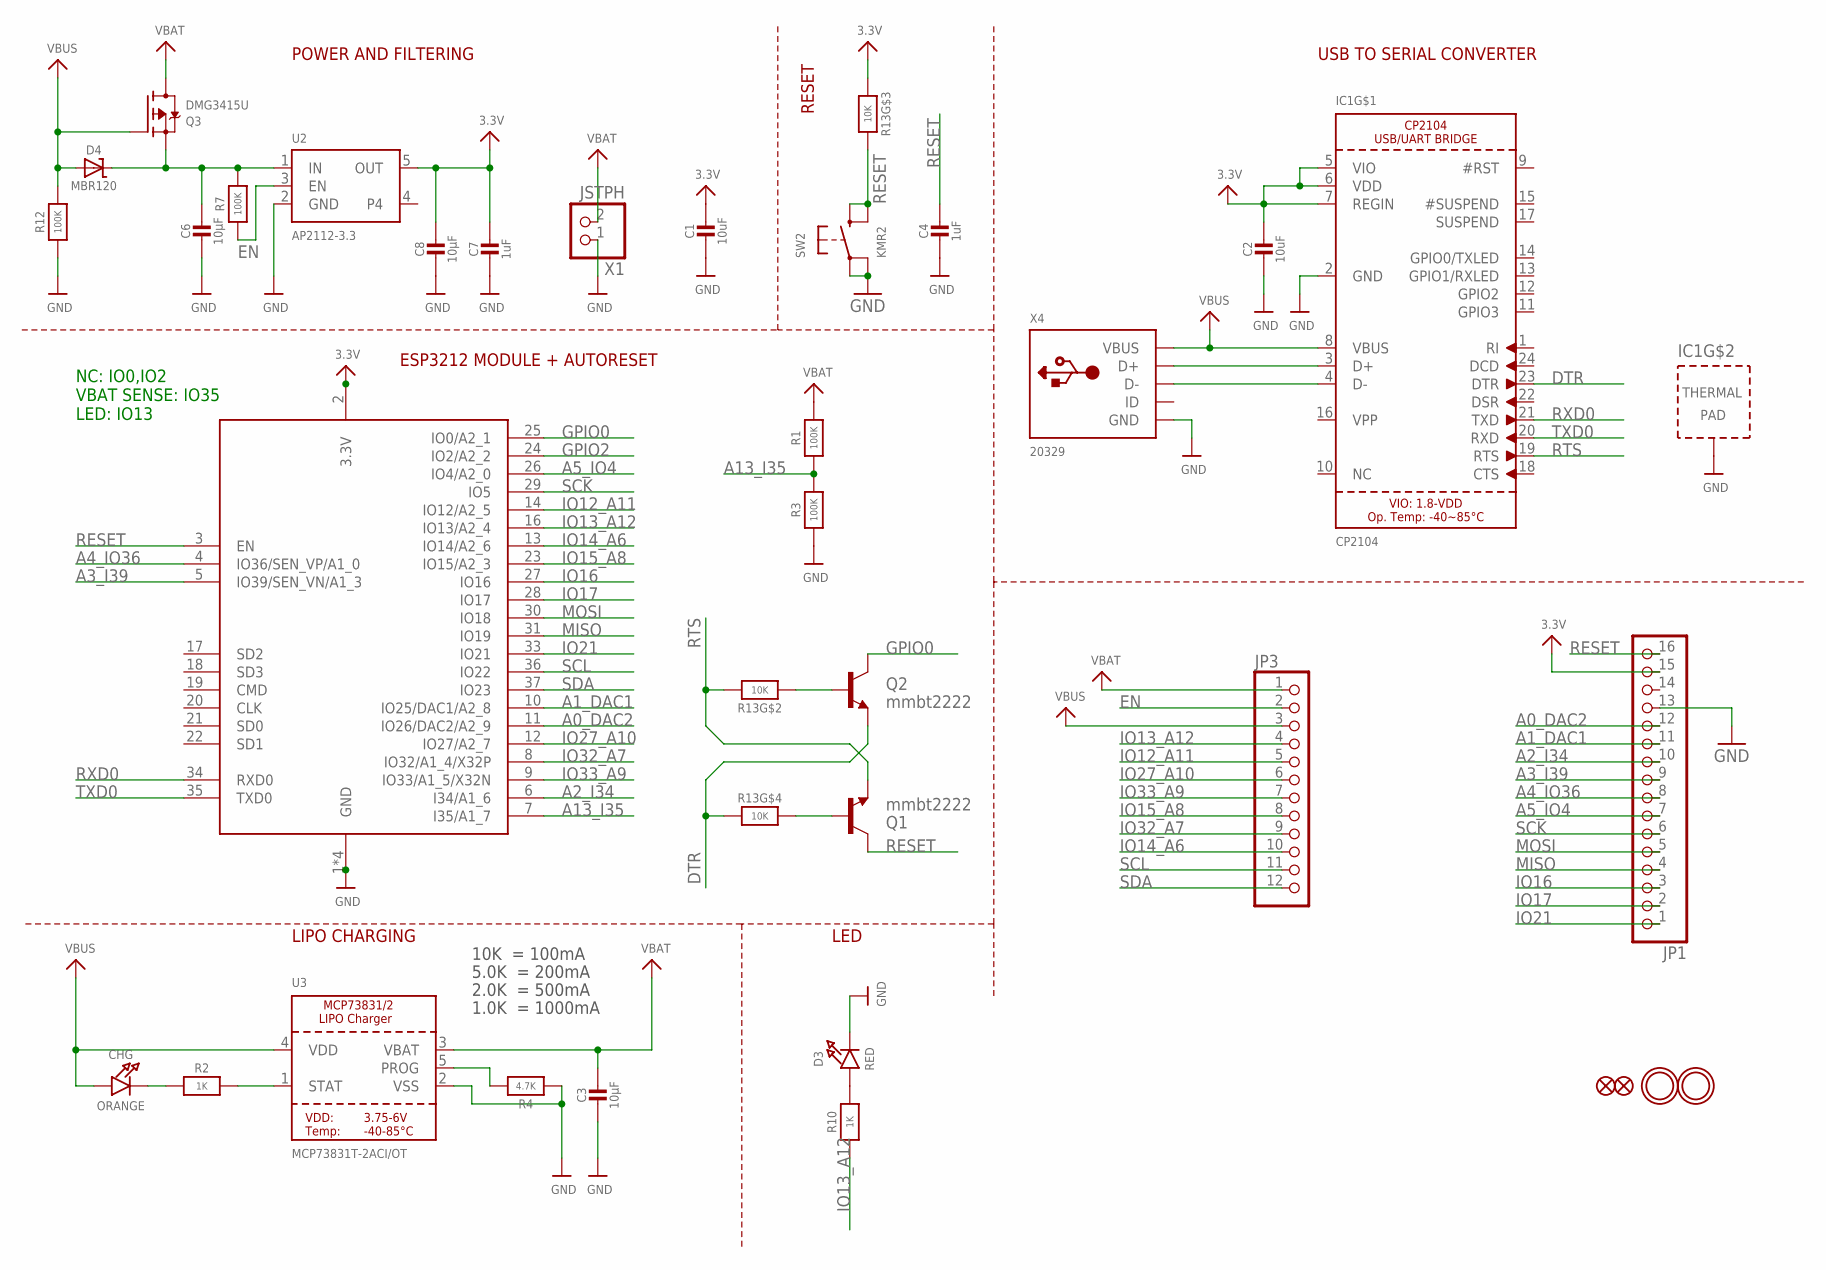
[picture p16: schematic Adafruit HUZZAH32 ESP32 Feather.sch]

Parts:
C1, C2: 10uF; 0805-NO
C3, C6, C8: 10µF; 0805-NO
C4, C7: 1uF; 0603-NO
CHG: ORANGE; CHIPLED_0805_NOOUTLINE
D3: RED; CHIPLED_0805_NOOUTLINE
D4: MBR120; SOD-123
IC1: CP2104; QFN24_4MM_SMSC
JP1: HEADER-1X16_MIN; 1X16_ROUND_MIN
JP3: HEADER-1X12_MIN; 1X12_ROUND_MIN
Q1, Q2: mmbt2222; SOT23-3
Q3: DMG3415U; SOT23-R
R1, R3, R7, R12: 100K; 0603-NO
R2, R10: 1K; 0603-NO
R4: 4.7K; 0603-NO
R13: 10K; RESPACK_4X0603
SW2: KMR2; BTN_KMR2_4.6X2.8
U2: AP2112-3.3; SOT23-5
U3: MCP73831T-2ACI/OT; SOT23-5
U$31, U$32: MOUNTINGHOLE2.5; MOUNTINGHOLE_2.5_PLATED
U$34, U$35: FIDUCIAL_1MM
X1: JSTPH; JSTPH2
X2: ESP32_WROOM32_SKINNY; WROOM32_SKINNY
X4: 20329; 4UCONN_20329_V2

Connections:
3.3V: C1.1, C2.1, C7.1, C8.1, IC1.5 (VIO), IC1.6 (VDD), IC1.7 (REGIN), JP1.15, R13.3 (1), U2.5 (OUT), X2.2 (3.3V)
A0_DAC2: JP1.12, X2.11 (IO26/DAC2/A2_9)
A1_DAC1: JP1.11, X2.10 (IO25/DAC1/A2_8)
A2_I34: JP1.10, X2.6 (I34/A1_6)
A3_I39: JP1.9, X2.5 (IO39/SEN_VN/A1_3)
A4_IO36: JP1.8, X2.4 (IO36/SEN_VP/A1_0)
A5_IO4: JP1.7, X2.26 (IO4/A2_0)
A13_I35: R1.1, R3.2, X2.7 (I35/A1_7)
DTR: IC1.23 (DTR), Q2.2 (E), R13.4 (1)
EN: JP3.2, R7.1, U2.3 (EN)
GND: C1.2, C2.2, C3.2, C4.2, C6.2, C7.2, C8.2, D3.C, IC1.2 (GND), IC1.THERM (TP), JP1.13, R3.1, R4.1, R12.1, SW2.A, SW2.A' (P1), U2.2 (GND), U3.2 (VSS), X1.1, X2.1 (GND), X2.15 (GND), X2.38 (GND), X2.P$1 (GND), X4.BASE@1 (GND), X4.BASE@2 (GND), X4.GND, X4.SPRT@1 (GND), X4.SPRT@2 (GND), X4.SPRT@3 (GND), X4.SPRT@4 (GND)
GPIO0: Q2.3 (C), X2.25 (IO0/A2_1)
GPIO2: X2.24 (IO2/A2_2)
IO12_A11: JP3.5, X2.14 (IO12/A2_5)
IO13_A12: JP3.4, R10.1, X2.16 (IO13/A2_4)
IO14_A6: JP3.10, X2.13 (IO14/A2_6)
IO15_A8: JP3.8, X2.23 (IO15/A2_3)
IO16: JP1.3, X2.27 (IO16)
IO17: JP1.2, X2.28 (IO17)
IO21: JP1.1, X2.33 (IO21)
IO27_A10: JP3.6, X2.12 (IO27/A2_7)
IO32_A7: JP3.9, X2.8 (IO32/A1_4/X32P)
IO33_A9: JP3.7, X2.9 (IO33/A1_5/X32N)
MISO: JP1.4, X2.31 (IO19)
MOSI: JP1.5, X2.30 (IO18)
unnamed: CHG.C, R2.1
unnamed: IC1.3 (D+), X4.D+
unnamed: R2.2, U3.1 (STAT)
unnamed: R4.2, U3.5 (PROG)
unnamed: D3.A, R10.2
unnamed: IC1.4 (D-), X4.D-
unnamed: C6.1, D4.C, Q3.2 (S), R7.2, U2.1 (IN)
unnamed: Q1.1 (B), R13.5 (2)
unnamed: Q2.1 (B), R13.2 (1)
RESET: C4.1, JP1.16, Q1.3 (C), R13.6 (2), SW2.B (S), SW2.B' (S1), X2.3 (EN)
RTS: IC1.19 (RTS), Q1.2 (E), R13.7 (2)
RXD0: IC1.21 (TXD), X2.34 (RXD0)
SCK: JP1.6, X2.29 (IO5)
SCL: JP3.11, X2.36 (IO22)
SDA: JP3.12, X2.37 (IO23)
TXD0: IC1.20 (RXD), X2.35 (TXD0)
VBAT: C3.1, JP3.1, Q3.3 (D), R1.2, U3.3 (VBAT), X1.2
VBUS: CHG.A, D4.A, IC1.8 (VBUS), JP3.3, Q3.1 (G), R12.2, U3.4 (VDD), X4.VBUS

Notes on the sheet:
POWER AND FILTERING
RESET
10K = 100mA
5.0K = 200mA
2.0K = 500mA
1.0K = 1000mA
USB TO SERIAL CONVERTER
LIPO CHARGING
LED
ESP3212 MODULE + AUTORESET
NC: IO0,IO2 VBAT SENSE: IO35 LED: IO13

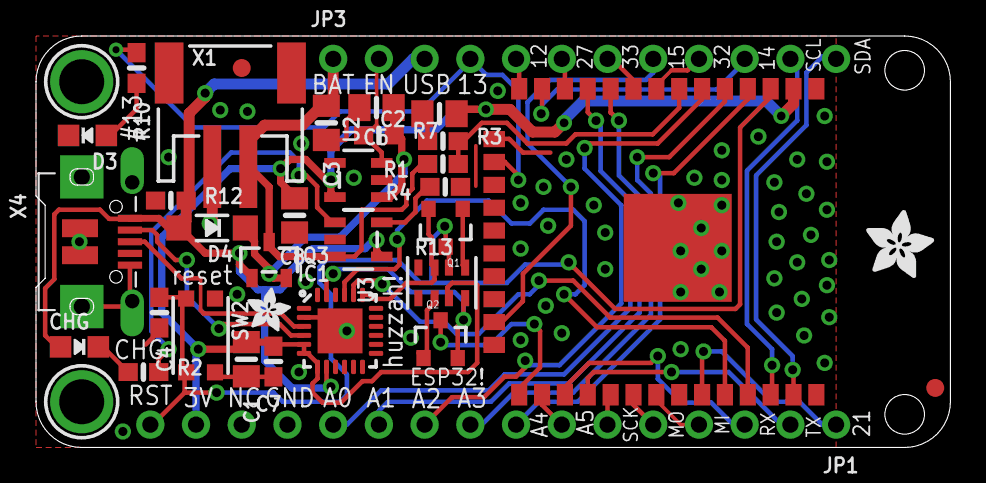
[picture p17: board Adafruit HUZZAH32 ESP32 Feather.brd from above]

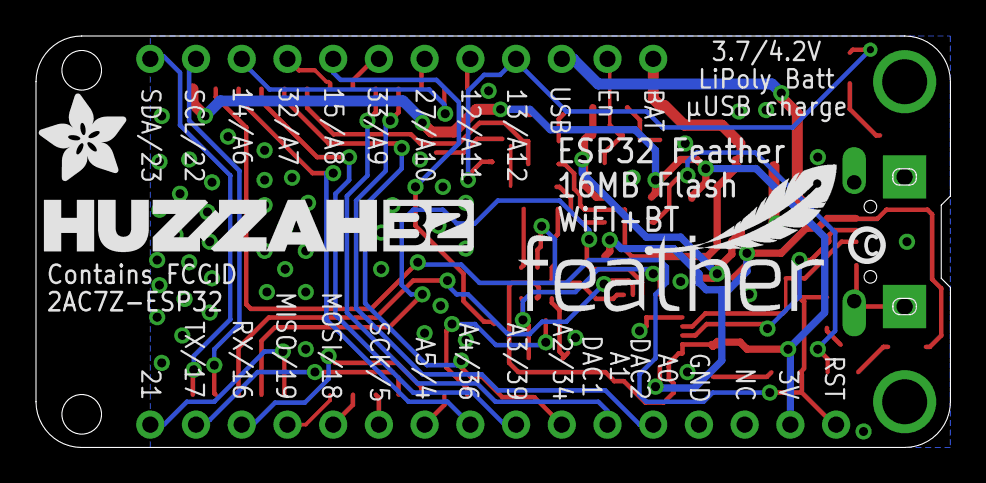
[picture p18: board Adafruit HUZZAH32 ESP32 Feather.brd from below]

Board: 2 copper layers, 50.8 x 22.9 mm, 40 parts (4 on the bottom side), 42 nets.

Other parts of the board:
U$7: ADAFRUIT_5MM
U$9: FEATHERLOGO_MED
U$13: PCBFEAT-REV-040
U$14: ADAFRUIT_2.5MM
U$15: ADAFRUIT_3.5MM
U$43: HUZZAH32

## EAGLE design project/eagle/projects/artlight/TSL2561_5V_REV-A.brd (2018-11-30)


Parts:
C2, C3: 10uF; 0805-NO
FID1, FID2: FIDUCIAL""; FIDUCIAL_1MM
JP1: HEADER-1X7THICKER; 1X07_ROUND_76
Q1, Q2: BSS138; SOT23-WIDE
R2, R3, R4, R5: 10K; 0805-NO
SJ1: SOLDERJUMPER_2WAY; SOLDERJUMPER_2WAY_OPEN_NOPASTE
U1: LIGHT_TSL2561; TSL2561_FN
U2: MIC5225-3.3; SOT23-5
U$18, U$19: MOUNTINGHOLE2.5; MOUNTINGHOLE_2.5_PLATED

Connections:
3.3V: C3.1, JP1.3, Q1.1 (G), Q2.1 (G), R2.2, R3.2, SJ1.1, U1.VDD (3.3V), U2.5 (OUT)
ADDR: JP1.4, SJ1.2, U1.ADR (ADDRSEL)
GND: C2.2, C3.2, JP1.2, SJ1.3, U1.VSS (GND), U2.2 (GND)
INT: JP1.5, U1.INT
SCL: Q2.2 (S), R3.1, U1.CLK (SCL)
SCL_5V: JP1.7, Q2.3 (D), R5.1
SDA: Q1.2 (S), R2.1, U1.DATA (SDA)
SDA_5V: JP1.6, Q1.3 (D), R4.1
VIN: C2.1, JP1.1, R4.2, R5.2, U2.1 (IN), U2.3 (EN)



Board: 2 copper layers, 19.1 x 16.5 mm, 18 parts (2 on the bottom side), 9 nets.

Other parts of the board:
U$15: ADAFRUIT_2.5MM
U$20: ADAFRUIT_5MM

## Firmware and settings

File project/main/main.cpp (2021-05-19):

#include "esp_log.h"

#include "nvs_flash.h"

#include "AsioTask.h"
#include "Event.h"
#include "I2C.h"
#include "MDNS.h"
#include "NVSKeyValueBroker.h"
#include "OtaTask.h"
#include "PeerTask.h"
#include "ProvisionTask.h"
#include "Preferences.h"
#include "Qio.h"
#include "SPI.h"
#include "TimeUpdate.h"
#include "WebSocketTask.h"
#include "Wifi.h"

// ArtLightApplication_h must be defined as the include file that declares
// the DerivedArtTask class
#include ArtLightApplication_h

// COMPONENT_EMBED_FILES start
extern char const preferencesFavicon0[]
			asm("_binary_preferencesFavicon_ico_start");
extern unsigned char const provisionCert0[]
			asm("_binary_provision_ca_cert_pem_start");
extern unsigned char const provisionKey0[]
			asm("_binary_provision_ca_key_pem_start");
extern char const provisionResponseFavicon0[]
			asm("_binary_provisionResponseFavicon_start");

// COMPONENT_EMBED_FILES end (no null terminator added)
extern char const preferencesFavicon1[]
			asm("_binary_preferencesFavicon_ico_end");
extern unsigned char const provisionCert1[]
			asm("_binary_provision_ca_cert_pem_end");
extern unsigned char const provisionKey1[]
			asm("_binary_provision_ca_key_pem_end");
extern char const provisionResponseFavicon1[]
			asm("_binary_provisionResponseFavicon_end");

// COMPONENT_EMBED_TXTFILES (null terminator added)
extern char const otaCertificate[]
			asm("_binary_ota_ca_cert_pem_start");
extern char const preferencesHtml[]
			asm("_binary_preferences_html_start");

class Main : public AsioTask {
public:
    asio::io_context::work work;

    NVSKeyValueBroker keyValueBroker;

    class Disconnected {
    public:
	Main & main;
	ProvisionTask provisionTask;
	Disconnected(Main & main_)
	:
	    main(main_),
	    provisionTask(
		provisionCert0, provisionCert1 - provisionCert0,
		provisionKey0 , provisionKey1  - provisionKey0 ,
		provisionResponseFavicon0,
		provisionResponseFavicon1 - provisionResponseFavicon0,
		main.keyValueBroker)
	{
	    ESP_LOGI(main.name, "Disconnected");
	    provisionTask.start();
	}
	~Disconnected() {
	    ESP_LOGI(main.name, "~Disconnected");
	}
    };
    std::unique_ptr<Disconnected> disconnected;

    class Connected {
    public:
	Main & main;
	MDNS mdns;
	TimeUpdate timeUpdate;
	OtaTask otaTask;
	Preferences preferences;
	PeerTask peerTask;
	WebSocketTask webSocketTask;
	Connected(Main & main_)
	:
	    main(main_),
	    mdns(main.keyValueBroker),
	    timeUpdate("timeUpdate", main.keyValueBroker),
	    otaTask(CONFIG_OTA_URL, otaCertificate, main.keyValueBroker),
	    preferences(preferencesHtml, main.keyValueBroker,
		preferencesFavicon0,
		preferencesFavicon1 - preferencesFavicon0),
	    peerTask(main.keyValueBroker),
	    webSocketTask(main.keyValueBroker)
	{
	    ESP_LOGI(main.name, "Connected");
	    otaTask.start();
	    peerTask.start();
	    webSocketTask.start();
	}
	~Connected() {
	    ESP_LOGI(main.name, "~Connected");
	}
    };
    std::unique_ptr<Connected> connected;

    Event::Loop eventLoopDefault;
    Event::Handler staGotIpHandler;
    Event::Handler staDisconnectedHandler;

    Wifi wifi;

    DerivedArtTask artTask;

    Main()
    :
	AsioTask{},	// this task

	work{io},

	keyValueBroker{"keyValueBroker"},

	disconnected{nullptr},
	connected{nullptr},

	eventLoopDefault{},

	staGotIpHandler{nullptr, IP_EVENT, IP_EVENT_STA_GOT_IP,
		[this](esp_event_base_t, int32_t, void *){
	    // we will get here after every successful esp_wifi_connect attempt
	    // *and* whenever our IP address has changed (new DHCP lease).
	    io.post([this](){
		disconnected.reset(nullptr);
		// we must always reset our connected object
		connected.reset(new Connected(*this));
	    });
	}},

	staDisconnectedHandler{nullptr, WIFI_EVENT, WIFI_EVENT_STA_DISCONNECTED,
		[this](esp_event_base_t, int32_t, void *){
	    // we will get here after every failed esp_wifi_connect attempt
	    io.post([this](){
		connected.reset(nullptr);
		// no need to reset our disconnected object
		// if we already have one
		if (!disconnected) {
		    disconnected.reset(new Disconnected(*this));
		}
	    });
	}},

	wifi{"WIFI"},

	artTask{keyValueBroker}
    {
	std::setlocale(LC_ALL, "en_US.utf8");

	// create LwIP task
	esp_netif_init();

	wifi.start();

	disconnected.reset(new Disconnected(*this));

	artTask.start();
    }

    ~Main() {}
};

extern "C"
void app_main() {
    // initialize Non-Volatile Storage.
    // this is used to save
    //	* Wi-Fi provisioning information
    //	* Application preferences
    ESP_ERROR_CHECK(nvs_flash_init());

    Main().run();
}

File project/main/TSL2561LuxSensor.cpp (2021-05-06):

#include "TSL2561LuxSensor.h"

#include <algorithm>
#include <cassert>
#include <cmath>
#include <vector>

#include <machine/endian.h>

#include "esp_log.h"

// https://ams.com/tsl2561

// scope of everything in this anonymous namespace
// is limited to this translation unit and has internal linkage
namespace {

enum Register: uint8_t {
    control		= 0x0,
    timing		= 0x1,
    lowThresholdLow	= 0x2,
    lowThresholdHigh	= 0x3,
    highThresholdLow	= 0x4,
    highThresholdHigh	= 0x5,
    interrupt		= 0x6,
    crc			= 0x8,
    id			= 0xa,
    channel0Low		= 0xc,
    channel0High	= 0xd,
    channel1Low		= 0xe,
    channel1High	= 0xf,
};

struct Command {
private:
    union {
	uint8_t	encoding;
	struct {
	    #if BYTE_ORDER == BIG_ENDIAN
		bool		command	:1;
		bool		clear	:1;
		bool		word	:1;
		bool		block	:1;
		unsigned	address	:4;
	    #else
		unsigned	address	:4;
		bool		block	:1;
		bool		word	:1;
		bool		clear	:1;
		bool		command	:1;
	    #endif
	};
    };
protected:
    Command(
	uint8_t	address_,
	bool	block_	= false,
	bool	word_	= false,
	bool	clear_	= false)
    :
	#if BYTE_ORDER == BIG_ENDIAN
	    command	(true),
	    clear	(clear_),
	    word	(word_),
	    block	(block_),
	    address	(address_)
	#else
	    address	(address_),
	    block	(block_),
	    word	(word_),
	    clear	(clear_),
	    command	(true)
	#endif
    {}
public:
    operator uint8_t() const {return encoding;}
};

struct ControlCommand : public Command {
public:
    ControlCommand() : Command{Register::control} {}
};

struct TimingCommand : public Command {
public:
    TimingCommand() : Command{Register::timing} {}
};

struct IdCommand : public Command {
public:
    IdCommand() : Command{Register::id} {}
};

struct ChannelCommand : public Command {
public:
    ChannelCommand(bool one) :
	Command{one
	    ? Register::channel1Low
	    : Register::channel0Low} {}
};

struct Control {
private:
    union {
	uint8_t	encoding;
	struct {
	    #if BYTE_ORDER == BIG_ENDIAN
		unsigned		:6;
		unsigned	power	:2;
	    #else
		unsigned	power	:2;
		unsigned		:6;
	    #endif
	};
    };
public:
    Control(bool power_)
    :
	power(power_ ? ~0 : 0)
    {}
    operator uint8_t() const {return encoding;}
};

struct IntegrationTime {
    uint8_t	encoding;
    float	value;
    unsigned	overflow;
};

static float constexpr normalIntegrationTime {402.0f};

static std::array<IntegrationTime, 3> constexpr integrationTimes {{
    {0b00,	normalIntegrationTime * 11.0f / 322.0f	,  4900}, // 5047},
    {0b01,	normalIntegrationTime * 81.0f / 322.0f	, 37000}, // 37177},
    {0b10,	normalIntegrationTime			, 65000}, // 65535},
}};

struct Gain {
    uint8_t	encoding;
    float	value;
};

static float constexpr normalGain {16.0f};

static std::array<Gain, 2> constexpr gains {{
    {0b0,	 1.0f},
    {0b1,	16.0f},
}};

// the cartesian product of two sets is the set of all pairs
template<typename I, typename J, typename O>
void cartesianProduct(I const & is, J const & js, O o) {
    for (auto i = std::begin(is); i != std::end(is); ++i) {
	for (auto j = std::begin(js); j != std::end(js); ++j) {
	    *o++ = std::make_pair(*i, *j);
	}
    }
}

// our sensitivities instance contains sorted pairs of integrationTime and gain
// encodings in increasing value product order.
static struct Sensitivities {
    using Pair = std::pair<IntegrationTime, Gain>;
    std::vector<Pair> pairs;
    Sensitivities() {
	cartesianProduct(integrationTimes, gains, std::back_inserter(pairs));
	std::sort(pairs.begin(), pairs.end(),
	    [](Pair const & a, Pair const & b) {
		return a.first.value * a.second.value
		     < b.first.value * b.second.value;
	    }
	);
    }
} const sensitivities;

struct Timing {
private:
    union {
	uint8_t	encoding;
	struct {
	    #if BYTE_ORDER == BIG_ENDIAN
		uint8_t				:2;
		uint8_t	gain			:1;
		uint8_t	manualStart		:1;
		uint8_t				:1;
		uint8_t	integrationTime	:2;
	    #else
		uint8_t	integrationTime	:2;
		uint8_t				:1;
		uint8_t	manualStart		:1;
		uint8_t	gain			:1;
		uint8_t				:2;
	    #endif
	};
    };
public:
    Timing(
	uint8_t	integrationTime_,
	uint8_t	gain_)
    :
	#if BYTE_ORDER == BIG_ENDIAN
	    gain		(gain_),
	    manualStart	(false),
	    integrationTime	(integrationTime_)
	#else
	    integrationTime	(integrationTime_),
	    manualStart	(false),
	    gain		(gain_)
	#endif
    {}
    operator uint8_t() const {return encoding;}
};

struct Id {
public:
    union {
	uint8_t	encoding;
	struct {
	    #if BYTE_ORDER == BIG_ENDIAN
		uint8_t	partNumber		:4;
		uint8_t	revisionNumber	:4;
	    #else
		uint8_t	revisionNumber	:4;
		uint8_t	partNumber		:4;
	    #endif
	};
    };
    Id(uint8_t encoding_) : encoding(encoding_) {}
    operator uint8_t() const {return encoding;}
};

}

TSL2561LuxSensor::TSL2561LuxSensor(
    asio::io_context &	io_,
    I2C::Master const *	i2cMaster_,
    uint8_t		address_)
:
    LuxSensor	{"TSL2561", io_},
    i2cMaster	{i2cMaster_},
    address	{address_},
    sensitivity	{0},
    startTime	{0}
{
    assertId();
    setSensitivity();
    start();
    timer.start();
}

// how long we should wait for commands to complete
static TickType_t constexpr wait = 1;

void TSL2561LuxSensor::assertId() const {
    uint8_t id;
    i2cMaster->commands(address, wait)
	.writeByte(IdCommand())
	.startRead()
	.readByte(&id)
    ;
    assert(id == 0x50);
}

void TSL2561LuxSensor::setSensitivity() const {
    auto pair = sensitivities.pairs[sensitivity];
    i2cMaster->commands(address, wait)
	.writeByte(TimingCommand())
	.writeByte(Timing(pair.first.encoding, pair.second.encoding));
}

void TSL2561LuxSensor::start() {
    i2cMaster->commands(address, wait)
	.writeByte(ControlCommand())
	.writeByte(Control(true));
    startTime = esp_timer_get_time();
}

void TSL2561LuxSensor::stop() const {
    i2cMaster->commands(address, wait)
	.writeByte(ControlCommand())
	.writeByte(Control(false));
}

unsigned TSL2561LuxSensor::tillAvailable() const {
    return sensitivities.pairs[sensitivity].first.value;
}

unsigned TSL2561LuxSensor::increaseSensitivity() {
    if (sensitivities.pairs.size() > sensitivity + 1) {
	++sensitivity;
	setSensitivity();
	stop();
	start();
    }
    return tillAvailable();
}

unsigned TSL2561LuxSensor::decreaseSensitivity() {
    if (0 < sensitivity) {
	--sensitivity;
	setSensitivity();
	stop();
	start();
    }
    return tillAvailable();
}
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

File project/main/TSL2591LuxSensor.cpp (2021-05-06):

#include "TSL2591LuxSensor.h"

#include <algorithm>
#include <cassert>
#include <cmath>
#include <limits>
#include <vector>

#include <machine/endian.h>

#include "esp_log.h"

// https://ams.com/tsl25911

// the data sheet uses the term "persistence" to give significance to
// an intensity change that been sustained for a configurable amount of time.
// unfortunately, they often use it in the negative sense as in "no persist"
// (a change has not persisted) or not at all (otherwise).
// this is confusing.
// instead, we use the term "stable" instead of "persistent"
// and "transient" instead of "non-persistent" or "immediate".
//
// the data sheet also uses the acronym ALS (Ambient Light Sensor?)
// without defining it.
// we say, simply, "sensor".

// scope of everything in this anonymous namespace
// is limited to this translation unit and has internal linkage
namespace {

enum Register: uint8_t {
    enable			= 0x00,
    control			= 0x01,
    stableLowThresholdLow	= 0x04,
    stableLowThresholdHigh	= 0x05,
    stableHighThresholdLow	= 0x06,
    stableHighThresholdHigh	= 0x07,
    transientLowThresholdLow	= 0x08,
    transientlowThresholdHigh	= 0x09,
    transientHighThresholdLow	= 0x0a,
    transientHighThresholdHigh	= 0x0b,
    stability			= 0x0c,
    packageId			= 0x11,
    id				= 0x12,
    status			= 0x13,
    channel0Low			= 0x14,
    channel0High		= 0x15,
    channel1Low			= 0x16,
    channel1High		= 0x17,
};

enum Function: uint8_t {
    interruptSet		= 0b00100,
    interruptClearStable	= 0b00110,
    intertuptClearBoth		= 0b00111,
    interruptClearTransient	= 0b01010,
};

enum Transaction: uint8_t {
    register_	= 0b01,
    function	= 0b11,
};

struct Command {
private:
    union {
	uint8_t	encoding;
	struct {
	    #if BYTE_ORDER == BIG_ENDIAN
		uint8_t	command		:1;
		uint8_t	transaction	:2
		uint8_t	address		:5;
	    #else
		uint8_t	address		:5;
		uint8_t	transaction	:2;
		uint8_t	command		:1;
	    #endif
	};
    };
protected:
    Command(
	uint8_t	address_,
	uint8_t transaction_ = register_)
    :
	#if BYTE_ORDER == BIG_ENDIAN
	    command	(1),
	    transaction	(transaction_),
	    address	(address_)
	#else
	    address	{address_},
	    transaction	{transaction_},
	    command	{1}
	#endif
    {}
public:
    operator uint8_t() const {return encoding;}
};

struct EnableCommand : public Command {
public:
    EnableCommand() : Command{Register::enable} {}
};

struct ControlCommand : public Command {
public:
    ControlCommand() : Command{Register::control} {}
};

struct IdCommand : public Command {
public:
    IdCommand() : Command{Register::id} {}
};

struct StatusCommand : public Command {
public:
    StatusCommand() : Command{Register::status} {}
};

struct ChannelCommand : public Command {
public:
    ChannelCommand(bool one) :
	Command{one
	    ? Register::channel1Low
	    : Register::channel0Low} {}
};

struct Enable {
private:
    union {
	uint8_t	encoding;
	struct {
	    #if BYTE_ORDER == BIG_ENDIAN
		uint8_t		transientInterrupt	:1;
		uint8_t		sleepAfterInterrupt	:1;
		uint8_t					:1;
		uint8_t		stableInterrupt		:1;
		uint8_t					:1;
		uint8_t		sensor			:1;
		uint8_t		oscillator		:1;
	    #else
		uint8_t		oscillator		:1;
		uint8_t		sensor			:1;
		uint8_t					:1;
		uint8_t		stableInterrupt		:1;
		uint8_t					:1;
		uint8_t		sleepAfterInterrupt	:1;
		uint8_t		transientInterrupt	:1;
	    #endif
	};
    };
public:
    Enable(
	bool oscillator_		= true,
	bool sensor_			= true,
	bool stableInterrupt_		= false,
	bool sleepAfterInterrupt_	= false,
	bool transientInterrupt_	= false)
    :
	oscillator		{oscillator_},
	sensor			{sensor_},
	stableInterrupt		{stableInterrupt_},
	sleepAfterInterrupt	{sleepAfterInterrupt_},
	transientInterrupt	{transientInterrupt_}
    {}
    operator uint8_t() const {return encoding;}
};

struct IntegrationTime {
    uint8_t	encoding;
    float	value;
    unsigned	overflow;
};

// static float constexpr normalIntegrationTime {400.0f};

static std::array<IntegrationTime, 6> constexpr integrationTimes {{
    {0b000,	100.0f,	36863},
    {0b001,	200.0f, 65535},
    {0b010,	300.0f, 65535},
    {0b011,	400.0f, 65535},
    {0b100,	500.0f, 65535},
    {0b101,	600.0f, 65535},
}};

struct Gain {
    uint8_t	encoding;
    float	value;
};

// static float constexpr normalGain {16.0f};

static std::array<Gain, 4> constexpr gains {{
    {0b00,	   1.0f},
    {0b01,	  24.5f},
    {0b10,	 400.0f},
    {0b11,	9200.0f},
}};

// the cartesian product of two sets is the set of all pairs
template<typename I, typename J, typename O>
void cartesianProduct(I const & is, J const & js, O o) {
    for (auto i = std::begin(is); i != std::end(is); ++i) {
	for (auto j = std::begin(js); j != std::end(js); ++j) {
	    *o++ = std::make_pair(*i, *j);
	}
    }
}

// our sensitivities instance contains sorted pairs of integrationTime and gain
// encodings in increasing value product order.
static struct Sensitivities {
    using Pair = std::pair<IntegrationTime, Gain>;
    std::vector<Pair> pairs;
    Sensitivities() {
	cartesianProduct(integrationTimes, gains, std::back_inserter(pairs));
	std::sort(pairs.begin(), pairs.end(),
	    [](Pair const & a, Pair const & b) {
		return a.first.value * a.second.value
		     < b.first.value * b.second.value;
	    }
	);
    }
} const sensitivities;

struct Control {
private:
    union {
	uint8_t	encoding;
	struct {
	    #if BYTE_ORDER == BIG_ENDIAN
		uint8_t	reset		:1;
		uint8_t			:1;
		uint8_t	gain		:2;
		uint8_t			:1;
		uint8_t	integrationTime	:3;
	    #else
		uint8_t	integrationTime	:3;
		uint8_t			:1;
		uint8_t	gain		:2;
		uint8_t			:1;
		uint8_t	reset		:1;
	    #endif
	};
    };
public:
    Control(
	uint8_t	integrationTime_,
	uint8_t	gain_,
	bool	reset_ = false)
    :
	#if BYTE_ORDER == BIG_ENDIAN
	    reset		{reset_},
	    gain		{gain_},
	    integrationTime	{integrationTime_}
	#else
	    integrationTime	{integrationTime_},
	    gain		{gain_},
	    reset		{reset_}
	#endif
    {}
    operator uint8_t() const {return encoding;}
};

struct Status {
    union {
	uint8_t	encoding;
	struct {
	    #if BYTE_ORDER == BIG_ENDIAN
		uint8_t				:2;
		uint8_t transientInterrupt	:1;
		uint8_t stableInterrupt		:1;
		uint8_t				:3;
		uint8_t available		:1;

	    #else
		uint8_t available		:1;
		uint8_t				:3;
		uint8_t stableInterrupt		:1;
		uint8_t transientInterrupt	:1;
		uint8_t				:2;
	    #endif
	};
    };
    Status(uint8_t encoding_) : encoding {encoding_} {}
};

}

TSL2591LuxSensor::TSL2591LuxSensor(
    asio::io_context &	io_,
    I2C::Master const *	i2cMaster_)
:
    LuxSensor		{"TSL2591", io_},
    i2cMaster		{i2cMaster_},
    sensitivity		{0}
{
    assertId();
    setSensitivity();
    start();
    timer.start();
}

// how long we should wait for commands to complete
static TickType_t constexpr wait {1};

void TSL2591LuxSensor::assertId() const {
    uint8_t id;
    i2cMaster->commands(address, wait)
	.writeByte(IdCommand())
	.startRead()
	.readByte(&id)
    ;
    assert(id == 0x50);
}
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

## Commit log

2018-12-01 SPI add necessary includes, flag_intr
2018-12-01 fix vTaskDelete synchronization issue with "statically" allocated TCB in Task object
    [ClockArtTask.cpp, LuxMonitorTask.cpp]
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2018-12-01 fix length of folded rendering transferred to message
    [ClockArtTask.cpp]
2018-12-06 buttons to fill preferences form with current OR default values
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2018-12-13 fix signature of ostream inserter to match usage
2018-12-28 add (2.6) gamma correction like Adafruit_DotStar implementation
    [ClockArtTask.cpp]
2018-12-31 ClockArtTask: fix copy/paste error on second rendering
    [ClockArtTask.cpp]
2019-01-17 publish hostname and web site through mDNS
    [partitions.csv]
2019-01-22 allow LED array creation, support new GammaEncode
2019-02-04 LEDC: Timer/Channel instance variables reduced to speed_mode and timer_num/channel
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2019-02-13 eagle artlight.cornhole board
    [artlight.cornhole.brd, artlight.cornhole.sch]
2019-02-13 pins artlight.cornhole
    [pins.ods]
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2019-02-14 eagle: artlight.cornhole: fix ground pour, add ledsw2
    [artlight.cornhole.brd, artlight.cornhole.sch]
2019-02-16 eagle: artlight.cornhole, pins
    [pins.ods]
2019-02-17 rename board -> artlight.board
2019-02-17 README.board.txt: add artlight.cornhole notes
2019-02-28 doc/README.board.txt: add artlight.cornhole board
2019-02-28 Pin: add move constructor
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2019-02-28 move Pin observation and LED handling into Ring
2019-02-28 fix LEDC timer and channel allocation
2019-02-28 animage a and b buttons
2019-03-01 led pulse with different relatively irrational frequencies
2019-03-06 Button: comment, refactor, tune
2019-03-07 Button refactor, rename, comment, tune
2019-03-07 SPI frequency 16M -> 8M to address noise
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2019-03-17 emit Button held when released after hold
2019-03-18 CornholeArtTask preferences/observers moved to arrays. Workaround ESP GPIO36 bug
    [CornholeArtTask.cpp, Pin.cpp]
2019-03-26 preferences: spectrum: disable cancel button, choose button text = OK
2019-03-28 preferences: make otaStart a button that submits otaUrl and starts OTA
2019-03-28 preferences: don't mess with button labels
2019-04-01 fix allocation bugs in LEDC.cpp
2019-04-02 WebSocket::acceptSession should std::forward socket instead of std::move it
2019-04-04 maximize ota app partition sizes
    [partitions.csv]
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2019-04-11 Dial.* -> Curve.*, add lighting strikes after hole event
2019-05-05 rename CornholeArtTask "Noise" mode to "Slide". add "Spin" mode
    [CornholeArtTask.cpp]
2019-05-06 CornholeArtTask Spin mode: fix wave position drift with time and changing width
    [CornholeArtTask.cpp]
2019-06-02 swap A and B (switch and LEDs)
    [CornholeArtTask.cpp]
2020-02-17 eagle ray project
    [ray.brd, ray.sch, ray0.brd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]
2020-02-22 catch update rate too fast
    [CornholeArtTask.cpp]
2020-02-25 make solder pads for LED strips more forgiving
    [ray.brd, ray.sch, ray0.brd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]
2020-03-10 folded clock with reverse capability
    [ClockArtTask.cpp]
2020-04-02 fix broken time after OTA update
    [ClockArtTask.cpp, CornholeArtTask.cpp]
2020-04-28 factor out LED dial stuff from ArtTask into DialArtTask from which both ClockArtTask and CornholeArtTask now derive from
2020-04-30 move SPI stuff out of ArtTask
2020-05-01 TLC59711 LED driver SPI interface
2020-05-06 move SPI and I2C setup to {Clock,Cornhole,Nixie}ArtTask constructors
2020-05-17 I2C writeBytes takes const data
2020-05-25 LuxSensor implementations keep track of startTime to detect underflow
2020-05-25 TSL2561LuxSensor throws underflow error on any raw channel == 0
    [TSL2561LuxSensor.cpp, TSL2591LuxSensor.cpp]
2020-05-29 change ClockArtTask timer back to 8 (from 12)
2020-06-02 LuxTask -> SensorTask, a shell task for synchronizing access to sensors
2020-06-03 avoid collisions between TSL*LuxSensor implementations with anonymous namespaces
    [TSL2561LuxSensor.cpp, TSL2591LuxSensor.cpp]
2020-06-09 nixie pins
    [pins.ods]
2020-06-18 change part number
    [bom.csv]
2020-07-24 add roll mode. map to nixie digits. blink colon. turn on LEDs
2020-07-25 PCA9685::Pwm default constructor sets offFull to 1
2020-07-25 default dots function returns 0. digitize{0,1} never returns more than 1. do not display hours 10 digit if 0. enforce minimum pwm
2020-07-25 create and use a simple PCA9685:Pwm operator that modifies itself using one unsigned value
2020-07-27 set brightness levels of LEDs and nixies, set color of top and bottome LEDs
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2020-07-27 make sure an LED level of 1 does not turn the LED off
2020-07-27 adjust level handling to limit LED range and resolve color selection
2020-07-29 characterize nixie tube brightness in our circuit
2020-07-30 maximum LED dimming (off when pitch black) as default
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2020-07-30 add nixie tube clock
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2020-07-31 make TSL2591 I2C device optional
2020-07-31 mark optional nixie tube clock parts
2020-08-01 README links to PCB design files
2020-08-02 nixie clock motion sensor is optional. default preference update
2020-08-06 APA102::Message constructor creates encodings from default LED constructor
2020-08-06 add preferences and behavior for motion sensor control
2020-08-08 set I2C clock for nixie sensor bus to 400000 (fast mode)
2020-08-13 Finally processing in I2C::Master::Commands desttuctor
2020-08-19 I2C::Master::Commands constructor asserts underlying link was created; destructor checks too
2020-08-20 I2C::Master::Commands destructor checks for successful construction
2020-08-20 revert to xtensa-esp32-elf-linux64-1.22.0-80-g6c4433a-5.2.0.tar.gz
2020-08-21 move sensorTask.start() to NixieArtTask::run()
2020-12-13 Pin.h disable pullups by default
2020-12-19 EasyEDA golden schematic and PCB artifacts
    [Gerber_BoardOutline.GKO, Gerber_BottomPasteMaskLayer.GBP, Gerber_BottomSilkLayer.GBO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]
2020-12-20 calculate the positioning and ordering LEDs in the spiral "strip"
2021-01-21 GoldenArtTask: increase LED resolution and use global scaling
2021-01-23 GoldenArtTask: apply noise to radius, stretch noise with contrast
    [GoldenArtTask.cpp]
2021-01-30 GoldenArtTask: fix wave rendering
    [GoldenArtTask.cpp]
2021-01-31 GoldenArtTask: wavePhase same for all dials, fix seam, break period for secondsDial
    [GoldenArtTask.cpp]
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2021-02-06 GoldenArtTask: compose rendering with int16_t precision, apply gamma correction, then encode
    [GoldenArtTask.cpp]
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2021-02-07 GoldenArtTask: do not gamma correct zero
    [GoldenArtTask.cpp]
2021-02-07 golden: make sure color dimming & gamma correction do not lose non-zero rgb parts
    [GoldenArtTask.cpp]
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2021-02-09 kicad snapeda libraries
2021-02-09 golden: kicad tinypico-io board
    [tinypico-io-B_Cu.gbr, tinypico-io-B_Mask.gbr, tinypico-io-B_Paste.gbr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]
2021-02-13 golden tinypico-io schematic update to use private modified symbols to pass ERC
    [tinypico-io.sch]
2021-02-13 golden tinypico-io update pcb from schematic
    [tinypico-io.kicad_pcb]
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2021-02-16 golden tinypico-io version 1.0.0
    [tinypico-io.kicad_pcb, tinypico-io.sch]
2021-02-16 golden tinypico-io gerbers version 1.0.0
    [tinypico-io-B_Cu.gbr, tinypico-io-B_Mask.gbr, tinypico-io-B_Paste.gbr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]
2021-02-16 golden tinypico-io footprint fixes
    [tinypico-io.kicad_pcb]
2021-02-16 golden tinypico-io footprint fixes, new gerbers
    [tinypico-io-B_Cu.gbr, tinypico-io-B_Mask.gbr, tinypico-io-B_Paste.gbr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]
2021-03-14 NixieArtTask.cpp: per Yan Zeyuan <support@nixie.ai>, wait 1 second before powering tubes
2021-05-06 LEDC.* compatible with ESP_IDF_VERSION >= ESP_IDF_VERSION_VAL(4, 0, 0)
2021-05-19 esp-idf v4.3-beta3: cmake, eclipse 2021-03, event loop upgrade, networking/wifi upgrade
    [Adafruit HUZZAH32 ESP32 Feather.brd, Adafruit HUZZAH32 ESP32 Feather.sch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]

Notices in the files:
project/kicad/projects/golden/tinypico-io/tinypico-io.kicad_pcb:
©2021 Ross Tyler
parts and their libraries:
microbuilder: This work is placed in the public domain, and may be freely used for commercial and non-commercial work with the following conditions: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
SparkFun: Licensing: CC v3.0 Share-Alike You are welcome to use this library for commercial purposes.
